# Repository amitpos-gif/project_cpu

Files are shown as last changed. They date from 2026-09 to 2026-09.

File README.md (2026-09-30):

# RISC-V RV32IM CPU Core & MCU — Structural VHDL

A fully functional five-stage pipelined RISC-V RV32IM processor designed from scratch in structural VHDL, taken through simulation, FPGA synthesis and on-hardware validation. The project is split into two parts: the pipelined CPU core, and a full MCU built on top of it.

---

## Projects

### 1. Pipelined RISC-V RV32IM CPU Core (`risc v cpu - project/`)

A five-stage pipelined implementation of the RISC-V RV32IM ISA (integer base + hardware multiply), built in structural VHDL from a single-cycle baseline.

**Pipeline stages:** IF → ID → EX → MEM → WB

**Key features:**
- Full data forwarding unit (EX/MEM and MEM/WB forwarding paths)
- Combinational hazard detection and stall unit
- Branch resolution with pipeline flush
- Hardware multiplier using the FPGA's embedded 8-bit multipliers (M extension)
- Structural HDL throughout — no behavioral shortcuts

**Verification & Validation:**
- Simulated in ModelSim against a RARS golden reference model
- IPC and functional correctness checked across a suite of test programs
- Mismatches analysed and debugged in simulation
- Synthesised and validated on an Intel FPGA with Signal-Tap on-hardware debug
- PPA (Power, Performance, Area) characterised and compared against the single-cycle baseline in Quartus

---

### 2. RV32IM-based MCU (`mcu - project/`)

An extension of the pipelined core into a full microcontroller unit.

**Added peripherals and features:**
- On-chip instruction and data memory
- Memory-mapped GPIO and I/O interface
- Vectored interrupt controller
- Hardware multicycle division accelerator with clock-domain-crossing synchronisation

---

## Tools & Flow

| Tool | Purpose |
|---|---|
| Intel Quartus | Synthesis, FPGA implementation, PPA analysis |
| ModelSim | RTL simulation and functional verification |
| Signal-Tap | On-hardware debug and signal probing |
| RARS | RISC-V golden reference model for verification |

**HDL:** Structural VHDL  
**Target FPGA:** Intel (Altera) FPGA  
**ISA:** RISC-V RV32IM

---

## Repository Structure

```
project_cpu/
├── risc v cpu - project/    # Five-stage pipelined RV32IM CPU core
│   ├── src/                 # VHDL source files (datapath, control, pipeline registers)
│   └── sim/                 # Simulation testbenches and scripts
└── mcu - project/           # Full MCU built on the pipelined core
    ├── src/                 # MCU peripherals and top-level integration
    └── sim/                 # MCU simulation files
```

---

## Background

Designed as part of the Advanced CPU Architecture course at Ben-Gurion University of the Negev, Hardware and VLSI & Semiconductor Devices tracks.

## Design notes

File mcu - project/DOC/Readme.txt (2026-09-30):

================================================================================
 RV32IM SINGLE-CYCLE MCU - FINAL PROJECT 2026
 Advanced CPU Architecture and Hardware Accelerators Lab 361-1-4693, BGU
 Submission: 206458333_318676061
================================================================================

 This file describes the content of every folder and subfolder in this
 submission, as required by clause 10 (Table 1) of the project definition.

 CONTENTS
   1. Submission tree at a glance
   2. DUT/     - synthesizable design sources
   3. TB/      - testbench
   4. SIM/     - ModelSim simulation script
   5. DOC/     - documentation
   6. Quartus/ - Quartus and hardware files
   7. How to reproduce the ModelSim simulation
   8. How to reproduce the Quartus compilation
   9. Conventions and things worth knowing

================================================================================
 1. SUBMISSION TREE AT A GLANCE
================================================================================

 206458333_318676061/
 |
 +-- DUT/
 |   +-- RV32IMscMCU/        32 synthesizable VHDL files (the design itself)
 |
 +-- TB/
 |   +-- RV32IMscMCU/        tb_mcu_top.vhd - the design testbench
 |
 +-- SIM/
 |   +-- RV32IMscMCU/        run_mcu_top.do - ModelSim compile + run script
 |
 +-- DOC/
 |   +-- Readme.txt          this file
 |   +-- Final_report.pdf    the full report (clause 9)
 |
 +-- Quartus/
     +-- RV32IMscMCU/        Signal-Tap file, SDC file and SOF file

 The RV32IMpipelinedMCU subfolders listed in Table 1 belong to the pipelined
 bonus task, which is not part of this submission, so they are not present.

================================================================================
 2. DUT/RV32IMscMCU  -  SYNTHESIZABLE DESIGN SOURCES
================================================================================

 Only design files - no testbench, no simulation script. All 32 files below
 compile without errors in ModelSim (VHDL-2008) and in Quartus.

 --- 2.1 Packages ------------------------------------------------------------

 cond_compilation_package.vhd
     The eight conditional-compilation parameters of the project: G_MODELSIM
     (1 = ModelSim, 0 = Quartus/FPGA), G_WORD_GRANULARITY, the ITCM/DTCM
     address width and word count (M9K / M4K variants), G_PC_WIDTH, G_MA_WIDTH
     and the three PLL divide/multiply ratios. Changing the memory
     configuration of the whole design is done here and only here.

 const_package.vhd
     Constants of the instruction set: opcodes, funct3/funct7 encodings, ALU
     operation codes and the immediate zero/one extension vectors used by
     IDECODE, EXECUTE and CONTROL.

 gpio_pkg.vhd
     The Table 5 memory map as named constants (PORT_LEDR 0x2000,
     PORT_HEX0..PORT_HEX5, PORT_SW 0x2010, PORT_PB 0x2014). It documents the
     address map in one place; the decoders themselves compare the address
     bits directly, which costs no logic.

 aux_package.vhd
     The central component-declaration registry of the project. Every entity
     in the design is declared here once, so a structural file only needs
     "use work.aux_package.all" instead of repeating component declarations.

 --- 2.2 Generic building blocks ---------------------------------------------

 BidirPin.vhd
     Bidirectional pin/bus driver. Used as the "Bi-directional Data BUS" block
     of Figure 1: it drives the shared byte bus during a CPU write and reads
     it back on every cycle.

 tristate_byte.vhd
     8-bit tri-state driver. Every peripheral read port uses one to place its
     byte on the shared Data bus when its chip select and MemRead are active.

 d_latch_byte.vhd
     8-bit transparent D-latch, the GPO register of Figure 5. It is
     transparent only while En = '1' AND clk = '0'; the low phase of SMCLK is
     the safe write window, after the single-cycle combinational chain has
     settled.

 hex7seg_decoder.vhd
     Converts the low nibble of a latched byte into an active-low 7-segment
     pattern for one HEX display.

 --- 2.3 CPU core ------------------------------------------------------------

 IFETCH.VHD
     Program counter, PC+4 adder, next-PC decision mux (reset / hold / jalr /
     branch-taken or jal / PC+4) and the ITCM, an altsyncram ROM initialized
     from a benchmark ITCM.hex file.

 IDECODE.VHD
     Instruction field extraction, the 32x32 register file, sign extension of
     all five immediate formats and the write-back mux (ALU / memory /
     multiplier / accelerator result).

 EXECUTE.VHD
     The ALU and the branch-address generation unit: all RV32I arithmetic,
     logic, shift and comparison operations, and the branch-taken decision.

 CONTROL.VHD
     Main control unit. Decodes the opcode into the datapath control signals
     and also implements the interrupt protocol side of the CPU: the PC hold,
     the INTA acknowledge cycle, the vector fetch and the GIE set/clear rules.

 DMEMORY.VHD
     The DTCM, an altsyncram single-port RAM initialized from a benchmark
     DTCM.hex file and clocked on NOT MCLK so that the address register is
     loaded with the write clock.

 MUL.vhd
     16-bit multiplier built from four 8-bit partial products, the RV32IM
     multiply extension.

 sync.vhd
     Two-flip-flop operand synchronizer (Figure 10b) that carries the two
     divider operands from the MCLK domain into the faster DIVCLK domain.

 divider_accelerator.vhd
     Unsigned restoring divider (Figure 9). DIVRST loads both operands in
     parallel and one quotient bit is produced on every enabled DIVCLK edge.

 RV32I_CORE.vhd
     Structural top of the CPU: IFETCH, IDECODE, EXECUTE, CONTROL, DMEMORY,
     MUL, sync and divider_accelerator, plus the divider handshake state
     machine, the MCLK cycle counter and the GIE / INTA / INTR interface to
     the interrupt controller.

 --- 2.4 Address decoders ----------------------------------------------------

 addr_decoder_gpio.vhd
     Chip selects for PORT_LEDR, PORT_HEX0/1, PORT_HEX2/3, PORT_HEX4/5 and
     PORT_SW.

 addr_decoder_basic_timer.vhd
     Chip selects for BTCTL1, BTCTL2, BTCMPR0, BTCMPR1 and BTCAPR.

 addr_decoder_interrupt.vhd
     Chip selects for IE (0x202C), IFG (0x202D) and TYPE (0x202E).

 --- 2.5 Peripherals ---------------------------------------------------------

 gpio_peripherals.vhd
     The GPIO block of Figure 5: the LEDR and HEX0..HEX5 D-latches, their
     7-segment encoders, the tri-state read-back drivers and the SW input
     port, all sharing one byte-wide Data bus.

 pushbutton_peripheral.vhd
     The KEY1..KEY3 input peripheral. It samples the buttons in the SMCLK
     domain, exposes their level as the read-only PORT_PB register (0x2014)
     and produces a one-cycle active-high press event per key for the
     interrupt controller.

 bit_Timer.vhd
     The N-bit up counter at the heart of the Basic Timer.

 OUTPUT_UNIT.vhd
     The output compare / PWM unit: the EQU0 and EQU1 comparators against
     BTCL0 and BTCL1 and the PWM output flip-flop, in both BTOUTMD modes.

 basic_timer.vhd
     The Basic Timer itself: the BTCTL1, BTCTL2, BTCMPR0, BTCMPR1 and BTCAPR
     registers, the BTSSEL clock-source divider, BTHOLD and BTCLR, the
     capture unit with its two-flip-flop crossing back into SMCLK, and the
     BTINT source selection that drives BTIFG.

 basic_timer_top.vhd
     Structural wrapper that joins basic_timer to its address decoder and
     qualifies the four writable registers with MemWrite.

 interrupt_controller.vhd
     The IE, IFG and TYPE registers, the event capture of BTIFG and the three
     key requests, the priority encoder (Basic Timer 0x10, KEY1 0x14,
     KEY2 0x18, KEY3 0x1C) and the INTR output.

 interrupt_controller_top.vhd
     Structural wrapper: the controller, its address decoder, and the bus
     interface that drives IE/IFG/TYPE on the Data bus for software reads and
     drives TYPE during the active-low INTA acknowledge, where no address is
     placed on the Address bus.

 --- 2.6 Clock tree and tops -------------------------------------------------

 PLL.vhd
     Altera altpll megafunction wrapper with configurable divide/multiply
     ratios. It is instantiated only when G_MODELSIM = 0, i.e. in Quartus.

 clock_tree.vhd
     The Clock Tree of Figure 1: three PLLs producing MCLK for the CPU, SMCLK
     for the peripherals and ACCELCLK (DIVCLK) for the divider accelerator,
     plus the combined locked indication.

 mcu_top.vhd
     The MCU: the RV32I core, the BUS Interface Logic (the ALU address tap,
     the bidirectional Data bus and the peripheral read-return path) and all
     peripherals - GPIO, pushbuttons, Basic Timer and interrupt controller.
     This is the entity the testbench instantiates.

 mcu_system.vhd
     The board-level top entity: the Clock Tree plus mcu_top, with the DE10
     pin names (CLOCK_50, KEY0..KEY3, SW, LEDR, HEX0..HEX5, PWM, CAPIN1/2).
     KEY0 is inverted into the active-high system reset, which is also held
     while the PLLs have not locked. This is the top entity for Quartus.

================================================================================
 3. TB/RV32IMscMCU  -  TESTBENCH
================================================================================

 tb_mcu_top.vhd
     The design testbench. It instantiates mcu_top and plays the role of the
     Clock Tree, because clock_tree only builds its PLLs when G_MODELSIM = 0
     and therefore has no outputs in simulation. It generates MCLK and SMCLK
     at 25 MHz, synchronous and in the same phase as d_latch_byte requires,
     and DIVCLK at 125 MHz, holds reset for five MCLK cycles and then lets
     the program in the ITCM run. KEY1..KEY3, SW, CAPIN1 and CAPIN2 start
     idle and can be driven from the ModelSim Objects/Wave window, or from
     the stimulus process, to exercise the peripherals and the interrupts.

================================================================================
 4. SIM/RV32IMscMCU  -  MODELSIM SIMULATION SCRIPT
================================================================================

 run_mcu_top.do
     The ModelSim script that builds and runs the simulation: it creates a
     fresh work library, compiles the packages, the core, the shared bus and
     GPIO, the Basic Timer and the interrupt system, then the testbench, all
     with vcom -2008; elaborates work.tb_mcu_top against the altera_mf
     library; opens a waveform grouped into CLOCKS AND RESET, CPU,
     PERIPHERAL BUS, INTERRUPTS and BOARD INPUTS AND OUTPUTS; and runs the
     simulation for 100 us.

     The design sources are read from ../../DUT/RV32IMscMCU and the
     testbench from ../../TB/RV32IMscMCU, through the DUTDIR and TBDIR
     variables at the top of the script, so it runs straight out of
     this folder without copying any file.

     See clause 7 below for how to run it.

================================================================================
 5. DOC  -  DOCUMENTATION
================================================================================

 Readme.txt
     This file: the description of every folder and subfolder of the
     submission.

 Final_report.pdf
     The full project report required by clause 9: the top-level block
     diagram, the RTL Viewer results, the three PPA tables (area,
     performance, power) with their Quartus screenshots, a short description
     of each HDL source file, the waveform analysis of benchmark applications
     test1 to test4, and the conclusions.

================================================================================
 6. Quartus/RV32IMscMCU  -  QUARTUS AND HARDWARE FILES
================================================================================

 test.sdc
     The Synopsys Design Constraints file. It creates the 20 ns (50 MHz)
     board clock on the CLOCK_50 port and then calls derive_pll_clocks and
     derive_clock_uncertainty so that TimeQuest also knows the three PLL
     output clocks of the Clock Tree.

 stp1.stp
     The Signal-Tap II logic analyzer file used for the on-board (ISMCE)
     verification: the instance, the sampling clock and the captured signal
     set used to record the MCU behaviour on the real FPGA.

 LAB_5_PIP.sof
     The SRAM Object File produced by the Quartus compilation, i.e. the
     bitstream downloaded to the DE10 board.

 No intermediate Quartus files (db, incremental_db, output_files, qsf, qpf)
 are included, as required by Table 1.

================================================================================
 7. HOW TO REPRODUCE THE MODELSIM SIMULATION
================================================================================

 The design uses sized bit-string literals (const_package) and "elsif
 generate" (IFETCH, RV32I_CORE), so VHDL-2008 is mandatory: every vcom call
 must carry -2008. It also uses altsyncram, so the altera_mf library must be
 available (it is precompiled in ModelSim - Intel FPGA Edition).

   1. Start ModelSim and set SIM/RV32IMscMCU as the working directory.
   2. At the ModelSim prompt:   do run_mcu_top.do
   3. The script reads the design from ../../DUT/RV32IMscMCU and the
      testbench from ../../TB/RV32IMscMCU, compiles everything into a
      fresh work library, opens the waveform and runs 100 us. Nothing
      has to be copied between the folders.

 Which benchmark program runs is decided by the init_file attribute of the
 two altsyncram instances - IFETCH.VHD for the ITCM and DMEMORY.VHD for the
 DTCM. Both hold an absolute path to a "bin/M9K-intel" folder of one
 benchmark application. To run a different test, point both paths at the
 ITCM.hex and DTCM.hex of that test and recompile those two files. A missing
 or mistyped path makes vsim stop with a fatal error at time 0.

================================================================================
 8. HOW TO REPRODUCE THE QUARTUS COMPILATION
================================================================================

   1. Create a Quartus project for the DE10 device and add all 32 VHDL files
      from DUT/RV32IMscMCU. Set the VHDL input version to VHDL 2008.
   2. Set mcu_system as the top-level entity.
   3. Set G_MODELSIM = 0 in cond_compilation_package.vhd so that clock_tree
      and RV32I_CORE instantiate the PLLs instead of taking the clocks
      directly from their input ports.
   4. Add test.sdc to the project as the timing constraint file.
   5. Compile, then program the board with the resulting SOF file, and open
      stp1.stp for the Signal-Tap capture.

================================================================================
 9. CONVENTIONS AND THINGS WORTH KNOWING
================================================================================

 * G_MODELSIM selects the whole build target. With G_MODELSIM = 1 the clocks
   arrive directly on the input ports, which is what the testbench drives;
   with G_MODELSIM = 0 the PLLs of the Clock Tree generate them.

 * SMCLK must be synchronous with MCLK and in phase with it. The GPIO output
   registers are transparent D-latches that open only while SMCLK is low, and
   that low phase is what guarantees the address and data have settled after
   the single-cycle combinational chain.

 * The peripheral Data bus is one shared byte-wide bidirectional bus. Every
   peripheral drives it through a tri-state and releases it to 'Z' otherwise,
   so at most one driver is ever active. BTCAPR is the exception: it is a
   32-bit word register and is returned to the CPU on a dedicated 32-bit path
   in mcu_top rather than through the byte bus.

 * Interrupt signal polarity: INTR and the key requests are active high, INTA
   is active low. During INTA the controller drives TYPE onto the Data bus
   without an address, which is why TYPE has priority over the address-decoded
   read paths in interrupt_controller_top.

 * Interrupt vectors: RESET/NMI type 0x00, Basic Timer type 0x10 (highest
   maskable priority), KEY1 type 0x14, KEY2 type 0x18, KEY3 type 0x1C
   (lowest). Bits 7:6 and 1:0 of IE and IFG are reserved and always read 0.

 * All peripheral addresses are byte addresses inside the 14-bit data address
   space; the I/O region starts at 0x2000.

================================================================================
 End of Readme.txt
================================================================================

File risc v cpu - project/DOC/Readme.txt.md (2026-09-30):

# Lab 5 — RV32IM Pipelined Processor (Course 361-1-4693, BGU)

This project converts the supplied **single-cycle RV32IM** core into a fully **pipelined 5-stage architecture** (IF · ID · EX · MEM · WB) written in **structural VHDL**. It supports the user-level RV32I instruction set plus the `MUL` extension, and targets the **DE10-Standard** board (Cyclone V `5CSXFC6D6F31C6`). The design adds hazard hardware (forwarding, load/MUL-use stalling, branch flush), a **2-stage pipelined multiplier**, an on-chip PLL for the core clock, and a SignalTap-oriented debug instrumentation layer. The authoritative datapath is the figure `rv32ipipeline.png`.

---

## Top Level

### `RV32I_CORE_PIPLINE.vhd`
Structural top of the pipeline core. Instantiates all five stages, the four pipeline registers, the three hazard units, the multiplier stages, and the PLL. Also contains two non-datapath blocks: a **debug shadow pipeline** that mirrors the instruction word and PC through EX/MEM/WB for observation (so the real registers needn't be widened), and the **instrumentation counters** (`CLKCNT`, `STCNT`, `FHCNT`) plus the SignalTap trigger (`STRIGGER`). Hazard enables are derived here: a stall freezes PC + IF/ID and bubbles ID/EX, while a flush squashes IF/ID, ID/EX and EX/MEM — with flush taking priority over stall.

### `PIPLINE_USER_INTERFACE.vhd`
Board-level wrapper for the DE10-Standard. Maps physical pins (`KEY` for reset/enable, `SW[7:0]` for the breakpoint address `BPADDR`) onto the core, applying reset polarity inversion. Internal taps are observed via SignalTap rather than driven to output pins.

---

## Pipeline Stages

### `IFETCH.VHD`  *(Stage 1 — IF)*
Fetches the instruction at the current PC from the ITCM and computes `PC+4`. Selects the next PC among `PC+4`, the branch/jump target, and the JALR target. **Branches and jumps are resolved at stage 4 (MEM)**, so the redirect inputs (`addr_gen`, `br_or_jump_taken`, `Jalr_ctrl`, `alu_res`) come from the *registered* EX/MEM outputs. PC advance is gated by the stall enable.

### `IDECODE.vhd`  *(Stage 2 — ID)*
Decodes the instruction, reads the register file, and generates the sign-extended immediate. The register-file **write port is driven by the retiring (MEM/WB) instruction** — write-back data, `rd`, `RegWrite`, `RegDst` and `PC+4` all arrive from MEM/WB, so the JAL/JALR link-address MUX inside this stage acts on the correct instruction.

### `EXECUTE.VHD`  *(Stage 3 — EX)*
Performs the ALU operation and computes the branch/jump target address (`adder_gen`). Contains the **operand-forwarding MUXes** for both ALU inputs (driven by `Forward_Ain`/`Forward_Bin` from the forwarding unit). The forwarded rs2 value is also captured for store data, with the ALUSrc MUX applied *after* forwarding on the B path so store addresses aren't corrupted. Launches **MUL stage 1** (the partial products) when `MULOp` is set.

### `DMEMORY.VHD`  *(Stage 4 — MEM)*
Data memory (DTCM, RAM). Reads/writes the word-addressed memory; the byte address from the ALU result is sliced (`>>2`) down to the DTCM word index. Store data is the forwarded rs2. Operates in parallel with **MUL stage 2** in this stage.

### `WB_MUX.vhd`  *(Stage 5 — WB)*
Write-back select. Chooses the value written to the register file among the **ALU result**, the **DTCM load data**, and the **MUL result** (the JAL/JALR PC+4 link is inserted on the IDECODE side). Controlled by `WBSrc`/`MemtoReg`.

---

## Pipeline Registers

Each register latches on the (PLL-derived) clock. `IF_ID` and `ID_EX` honor stall (hold/bubble) and flush; `EX_MEM` honors flush; all reset to a NOP-equivalent state.

| File | Boundary | Key payload carried |
|---|---|---|
| `IF_ID_REG.vhd` | IF → ID | `pc`, `pc_plus4`, `instruction` (+ `ena`/`flush`) |
| `ID_EX_REG.vhd` | ID → EX | `pc`, `pc_plus4`, `read_data1/2`, `imm32`, `rs1/rs2/rd`, full control bundle (`ALUOp`, `ALUSrc`, `UpperImm`, `MULOp`, `Branch`, `Jal`, `Jalr`, `MemRead/Write`, `RegWrite`, `MemtoReg`, `RegDst`, `WBSrc`) |
| `ex_mem_reg.vhd` | EX → MEM | `pc_plus4`, `read_data1/2`, `imm32`, `rs1/rs2/rd`, `Alu_Res`, `Adder_gen`, MUL stage-1 partials `p0..p3`, `MULOp`, `br_or_jump_taken`, `Jalr_ctrl`, and MEM/WB control |
| `MEM_WB_REG.vhd` | MEM → WB | `pc_plus4`, `alu_res`, `mem_data`, `mul_res`, `rd`, `RegWrite`, `MemtoReg`, `RegDst`, `WBSrc` |

---

## Hazard Hardware

### `forwarding_unit.vhd`
Compares the ID/EX source registers (`rs1`, `rs2`) against the destination registers in **EX/MEM** and **MEM/WB** (gated by their `RegWrite`), emitting 2-bit `Forward_Ain`/`Forward_Bin` selects to bypass operands into EXECUTE. Resolves EX-hazards (one ahead) and MEM-hazards (two ahead) without stalling.

### `STALL_UNIT.vhd`
Detects the **load-use** and **MUL-use** interlocks: if the instruction in EX is a load (`MemRead`) or a multiply (`MULOp`) and its `rd` matches an `rs1`/`rs2` of the instruction in IF/ID, it asserts `Stall` for one cycle (freeze PC + IF/ID, bubble ID/EX) — the case forwarding alone cannot cover.

### `FLUSH_UNIT.vhd`
Generates the squash signal when a branch/jump (or JALR) is **taken**, reading the *registered* EX/MEM redirect bits (resolution at stage 4). The flush kills the wrong-path instructions sitting in IF/ID, ID/EX and EX/MEM.

---

## Multiplier (2-stage)

### `MUL_STAGE1.VHD`
Runs in **EX**. Produces the four 16-bit partial products (`p0..p3`) from the operands; these are carried through EX/MEM.

### `MUL_STAGE2.VHD`
Runs in **MEM**. Combines the partial products into the final 32-bit result, preserving the full-width intermediate carry. The result feeds the WB MUX.

---

## Clocking & Memory

### `PLL.vhd`
Altera ALTPLL megafunction. On the FPGA it converts the **50 MHz** board clock to the **75 MHz** core clock (×3 ÷2). In ModelSim the PLL is bypassed (`mclk = clk_i`) via the `MODELSIM` generate guard.

### Memory (ITCM / DTCM)
Word-addressed on-chip memories initialized from Intel-HEX files. Instruction memory lives inside `IFETCH`; data memory is `DMEMORY.VHD`.

---

## Support Packages

| File | Role |
|---|---|
| `aux_package.vhd` | Component declarations for all entities (structural binding). |
| `const_package.vhd` | Global constants / widths (`G_PC_WIDTH`, `G_ADDRWIDTH`, `G_DATA_WORDSNUM`, …). |
| `cond_compilation_package.vhd` | Conditional-compilation switches (e.g. `G_MODELSIM`, `G_WORD_GRANULARITY`). |
| `CONTROL.VHD` | Main control decoder: maps opcode/funct of the IF/ID instruction to the full control bundle. |

---

## Debug & Instrumentation

The core exposes per-stage **PC** and **instruction** taps (`IFpc`/`IFinstruction` … `WBpc`/`WBinstruction`), free-running `CLKCNT`, stall counter `STCNT`, flush counter `FHCNT`, and a `STRIGGER` pulse when the IF-stage PC (word index) equals `BPADDR`. The EX/MEM/WB instruction and PC taps are produced by an observation-only **shadow pipeline** that mirrors the bubble/hold behavior of the real registers.

---

## Toolchain

- **Quartus Prime** — synthesis, place-and-route, pin assignment, programming.
- **ModelSim Intel FPGA Edition** — RTL/gate simulation.
- **TimeQuest** — static timing analysis (PLL-derived clock constrained via `derive_pll_clocks`).
- **SignalTap** — in-system observation of the stage taps and counters.

---

## Hardware Test Case

Tested on the **DE10-Standard** FPGA board: `KEY` buttons drive reset/enable, `SW[7:0]` set the breakpoint address (`BPADDR`), and SignalTap captures the pipeline state when the IF-stage PC reaches the breakpoint.

---

By: yuval elron and amit postelnik

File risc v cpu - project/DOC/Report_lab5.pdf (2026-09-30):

# Laboratory 5 Report

Conversion of a Single-Cycle RV32IM Processor into a Five-Stage Pipelined Micro-Architecture

Submitted by | Yuval Elron – 318676061 Amit Postelnik – 206458333
Course | Advanced CPU Architecture & Hardware Accelerators (361-1-4693)
Target Device | Intel Cyclone V 5CSXFC6D6F31C6 (DE10-Standard)
Tool-chain | Quartus Prime 21.1 Lite • ModelSim • TimeQuest • SignalTap
ISA | RV32IM (MULDIV partial)
Report file | Report_lab5.pdf

Lab 5 – RV32IM Pipelined Processor | Report_lab5.pdf

## 1. Introduction and Lab Context

This report documents the conversion of a single-cycle RV32IM (MULDIV-partial) processor into a fully pipelined five-stage RISC-V micro-architecture, implemented in structural VHDL and synthesised for the Intel Cyclone V FPGA on the DE10-Standard board. The single-cycle design delivered in the previous task served as the functional reference: its datapath was sliced into the five classical RISC pipeline stages – Instruction Fetch (IF), Instruction Decode / register read (ID), Execute / address calculation (EX), Data-Memory access (MEM) and Write-Back (WB) – with pipeline registers inserted at every stage boundary.

Pipelining overlaps the execution of consecutive instructions so that, in steady state, one instruction is retired every clock cycle. Because each stage now performs only a fraction of the original combinational work, the critical path is dramatically shortened and the maximum operating frequency increases substantially. This benefit is not free: overlapping execution introduces data hazards (an instruction needing a result that has not yet been written back) and control hazards (the next fetch address depending on a branch that has not yet resolved). The design therefore adds three pieces of dedicated hazard hardware: a forwarding (bypass) unit that routes freshly computed results back to the EX stage, a combinational stall-detection unit that inserts bubbles for the unavoidable load-use and multiply-use cases, and a flush unit that squashes wrong-path instructions once a branch or jump is resolved.

In accordance with the lab specification, conditional branches and unconditional jumps are resolved in pipeline stage 4 (MEM), and the multiplier is split across two pipeline stages (partial-product generation in EX, accumulation in MEM) so that it does not dominate the critical path. The remainder of this report presents the top-level structure, the RTL-Viewer netlists, a quantitative Power–Performance–Area (PPA) comparison between the single-cycle and pipelined designs, a description of every HDL source file, and an analysis of the simulation waveforms used to validate system timing against the benchmark applications.

## 2. Top-Level Block Review Diagram

The synthesised top-level entity is PIPLINE_USER_INTERFACE, the board wrapper that adapts the logical core (RV32I_CORE_PIPLINE) to the physical DE10-Standard pins. The wrapper exposes only three input ports – the 50 MHz oscillator CLOCK_50, the active-low push-buttons KEY[3:0]
(KEY0 is inverted to form the active-high reset), and the slide switches | (the lower eight feed
the breakpoint address BPADDR_i). It has no output ports: all observability is provided internally through SignalTap taps (CLKCNT_o, STCNT_o, FHCNT_o and the core buses), which is why the pin count drops sharply relative to the single-cycle top entity.
Internally the core is a structural composition of fourteen sub-modules: a PLL (50 MHz →
core clock), the five stage blocks (Ifetch, Idecode, Execute, dmemory, write-back MUX), the four pipeline registers (IF_ID_REG, ID_EX_REG, EX_MEM_REG, MEM_WB_REG), the control decoder, and the three hazard units (FORWARDING_UNIT, STALL_UNIT, FLUSH_UNIT). The two-stage multiplier is embedded inside the EX and MEM blocks. Figure 1 shows the top-level RTL-Viewer elaboration of this wrapper, which acts as the block-review diagram of the complete design.

SW[7:0]

25 MHz

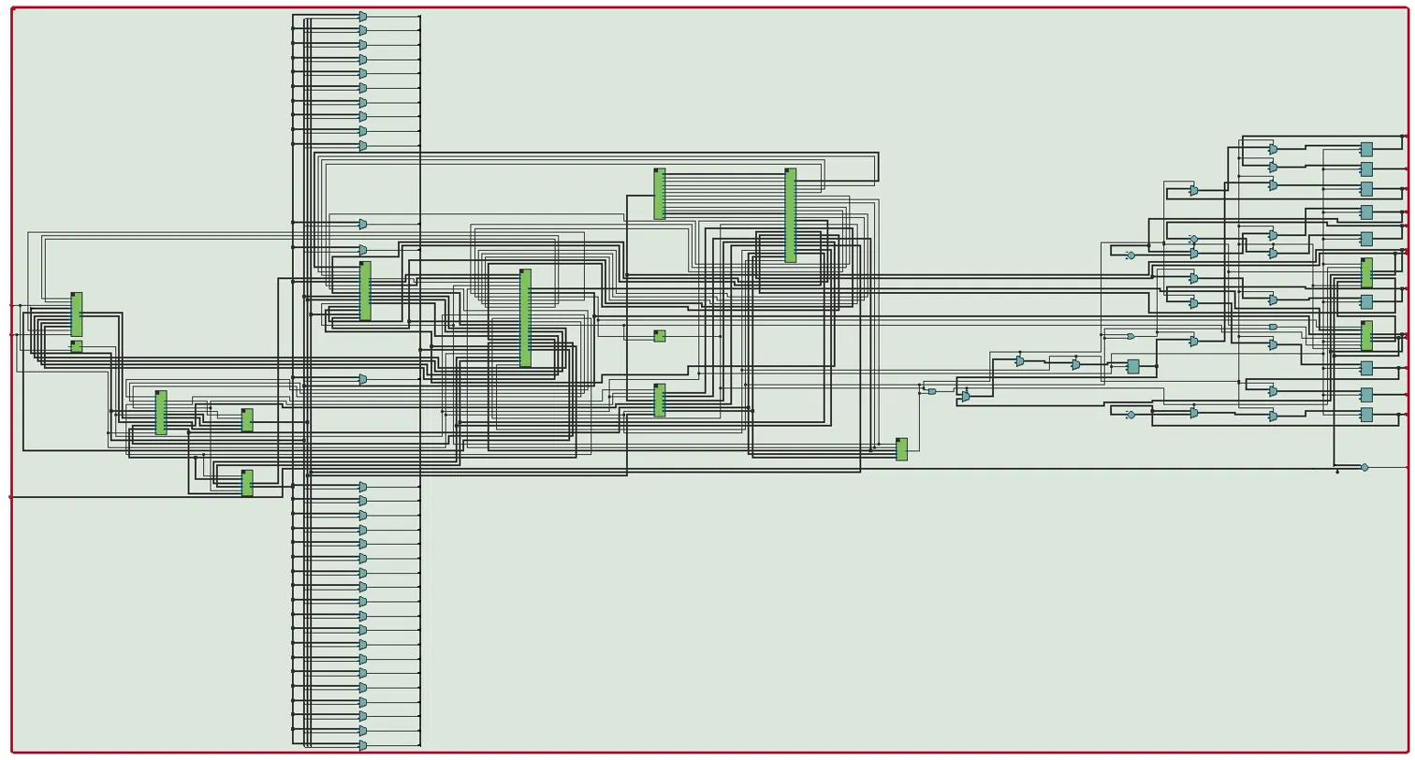
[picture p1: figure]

Figure 1: Top-level block / RTL elaboration of the pipelined RV32IM design (PIPLINE_USER_INTERFACE), showing the five pipeline stages separated by pipeline registers and the surrounding hazard logic.

## 3. RTL Viewer Results

The Quartus RTL Viewer presents the post-elaboration, technology-independent netlist inferred from the VHDL source. Comparing the two designs makes the structural effect of pipelining explicit. In the single-cycle netlist (Figure 2) the datapath forms one long combinational chain from the instruction memory, through the register file and ALU, to the data memory and back to the register file, with no intermediate state. In the pipelined netlist (Figure 3) that chain is interrupted by four banks of pipeline registers, partitioning the logic into five shorter stages and adding the forwarding, stall and flush logic that connects across stage boundaries.

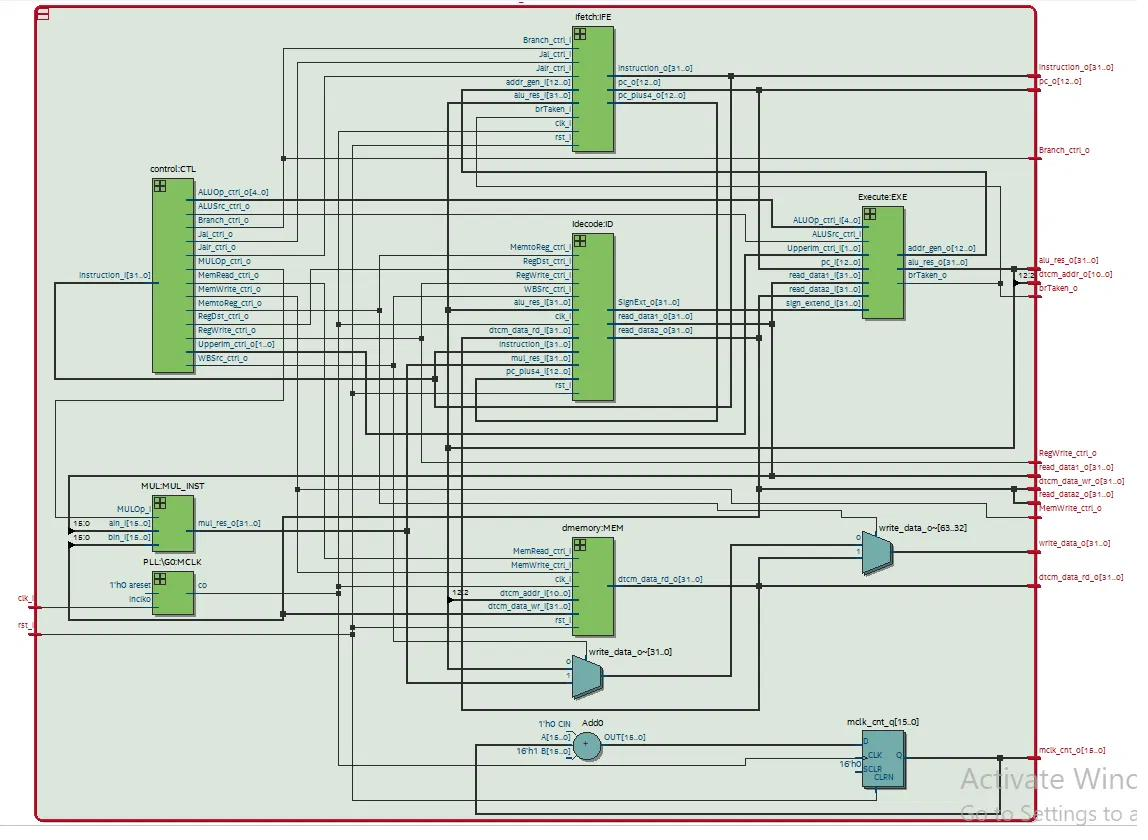
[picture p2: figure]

Figure 2: RTL-Viewer netlist of the original single-cycle RV32IM design. The datapath is a single combinational path with no pipeline registers.

Figure 3: RTL-Viewer netlist of the pipelined RV32IM design. Four pipeline-register banks split the datapath into five stages; additional hazard logic bridges the stage boundaries.

## 4. Clause 7 – PPA Characterisation (Area, Performance, Power)

This section reports the three Power–Performance–Area tables required by clause 7, each comparing the single-cycle and pipelined implementations. The figures are taken directly from the Quartus Fitter, TimeQuest and Power-Analyzer reports, whose screen captures are attached immediately after each table as mandated by the specification.

### 4.1 Area

Area

| Logic elements | Registers | I/O pins | Embedded memory bits | Embedded 9-bit Multipliers | PLLs
Single-Cycle RV32IM | 1,436 | 1,311 | 270 | 131,072 | 3 | 1
Pipelined RV32IM | 1,456 | 1,760 | 15 | 131,072 | 4 | 1

Note: Attaching the print screen of the Quartus Area report is mandatory
Table 1: Area / resource utilisation of the single-cycle versus pipelined RV32IM designs (Quartus Fitter Flow Summary).

The pipeline adds ~449 registers (1,311 → 1,760), the cost of the four pipeline-register banks, while combinational logic grows only marginally (1,436 → 1,456 logic elements). The embedded 9-bit multiplier count rises from 3 to 4 because the multiplier is now split across two stages. The pin count collapses from 270 to 15 because the pipelined top entity exposes only the clock, keys and switches and relies on internal SignalTap taps rather than routing buses to physical pins.

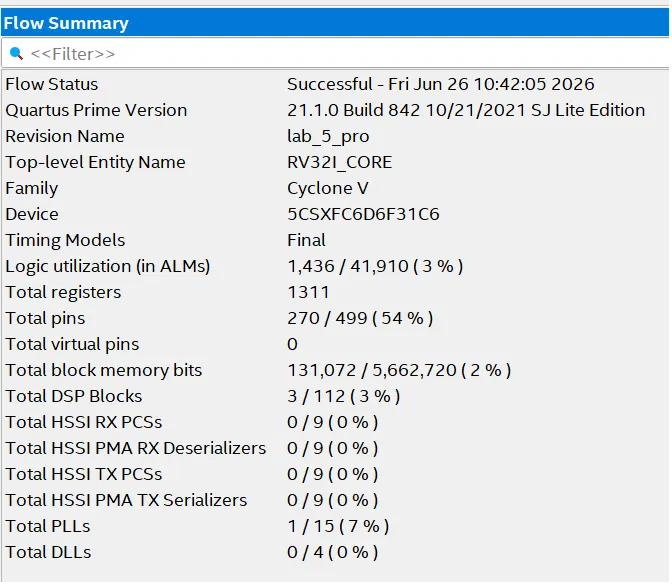
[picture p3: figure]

Figure 4: Quartus Flow Summary (area) report – single-cycle RV32IM.

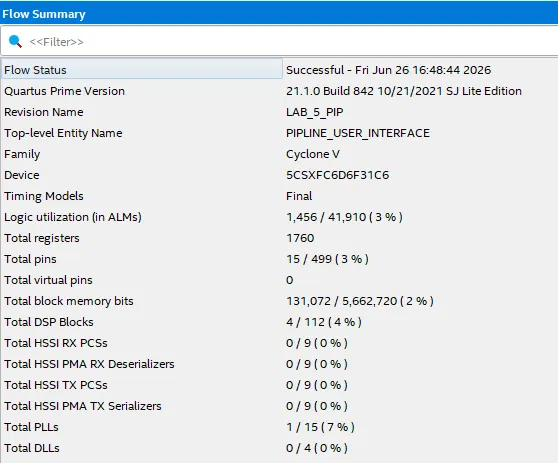
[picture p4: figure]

Figure 5: Quartus Flow Summary (area) report – pipelined RV32IM.

### 4.2 Performance (fmax

### and Critical Path)

Performance

| fmax | Critical path (what is the slowest submodule and why does it cause the critical path) | f MCLK (= fsysclk)
Single-Cycle RV32IM | 38.05 MHz | Long path: DTCM read → decode → Execute ALU/shifter mux chain (brl_shr / Mux60). Memory access, decode and execution all fall inside one cycle.
Pipelined RV32IM | 70.32 MHz | Path: DTCM (data_memory) read port q_a[31:0] → MEM_WB_REG. Stage isolation removes the memory–decode–execute chain, so the memory read alone now sets the limit.

Table 2: Performance comparison: maximum clock frequency and critical-path analysis (Quartus TimeQuest).

Pipelining nearly doubles fmax

(38.05 → 70.32 MHz). The theoretical upper bound for a perfectly balanced 5-stage pipeline is 5 × f

single; the realised speed-up is lower because the stages are not perfectly balanced – the synchronous DTCM read, feeding the MEM/WB register, is the slowest stage and now defines the critical path, as confirmed by the Map-Viewer trace below.

Figure 6: Quartus TimeQuest f
max

report – single-cycle RV32IM (38.05 MHz).

Figure 7: Quartus TimeQuest f
max

report – pipelined RV32IM (70.32 MHz).

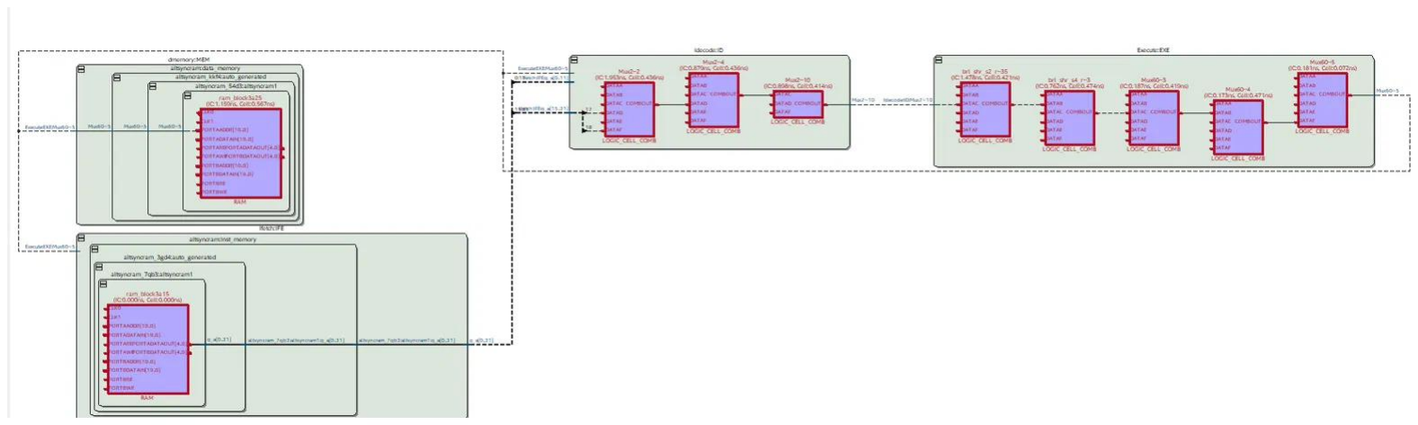
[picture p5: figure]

Figure 8: Critical-path Technology-Map Viewer – single-cycle: the path spans data memory, the decode stage and the Execute ALU/shifter mux chain.

25 MHz

25 MHz

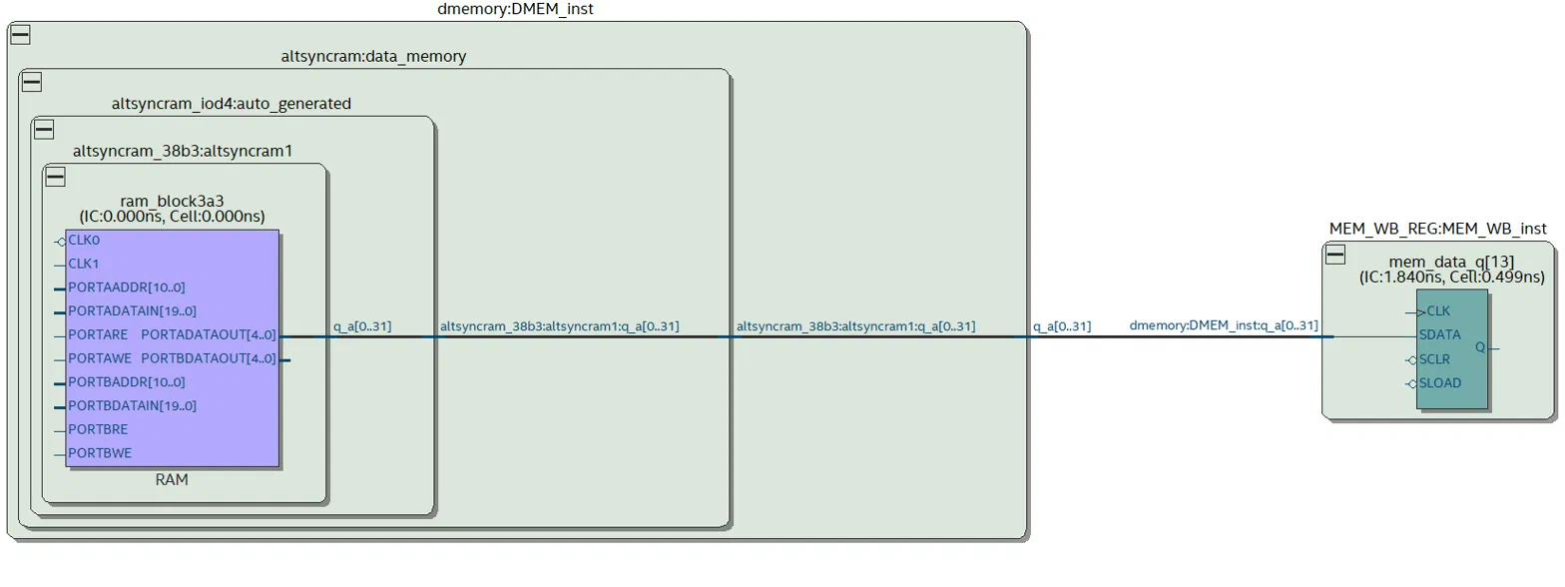
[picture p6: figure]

Figure 9: Critical-path Technology-Map Viewer – pipelined: the path is reduced to the DTCM read port feeding the MEM_WB_REG register.

### 4.3 Power

Power

| Total power consumption | Static power consumption | Dynamic power consumption | I/O power consumption
Single-Cycle RV32IM | 448.06 mW | 415.31 mW | 19.01 mW | 13.74 mW
Pipelined RV32IM | 447.79 mW | 415.31 mW | 22.38 mW | 10.10 mW

Note: Attaching the print screen of the Quartus Power report is mandatory
Table 3: Power-dissipation comparison (Quartus PowerPlay Power Analyzer, thermal power).

Total dissipation is essentially unchanged (≈448 mW) and is dominated by the device static power (415.31 mW), which is identical for both designs because it depends on the Cyclone V silicon rather than the logic. Core dynamic power rises slightly in the pipeline (19.01 → 22.38 mW) due to the extra register toggling, while I/O power falls (13.74 → 10.10 mW) because far fewer pins are driven. As noted in both reports, the estimation confidence is Low because no switching-activity (toggle-rate) file was supplied, so the dynamic figures should be read as first-order estimates.

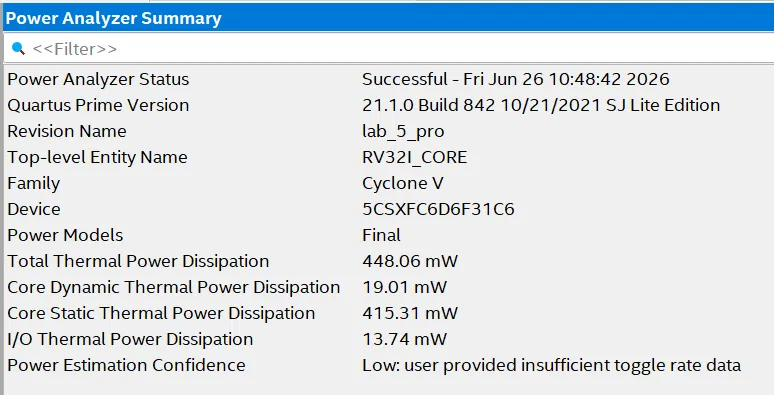
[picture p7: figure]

Figure 10: Quartus Power-Analyzer report – single-cycle RV32IM.

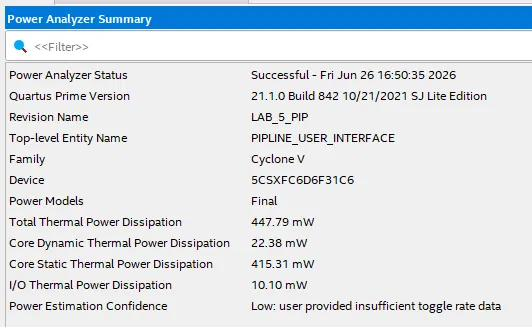
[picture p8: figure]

Figure 11: Quartus Power-Analyzer report – pipelined RV32IM.

## 5. HDL Source File Descriptions

The design is fully structural: a top wrapper instantiates the core, which in turn instantiates the stage blocks, pipeline registers and hazard units. Table 5 lists every HDL source file with a short description of its role in the pipeline.

HDL Source File | Description
PIPLINE_USER_INTERFACE.vhd | Board top-level wrapper for the DE10-Standard. Maps CLOCK_50, KEY[3:0] and SW[9:0] to the core; inverts KEY0 to an active-high reset and routes SW[7:0] to the breakpoint address. No output ports – internal signals are observed via SignalTap.
RV32I_CORE_PIPLINE.vhd | The logical pipelined core. Structurally instantiates the PLL, the five stage blocks, the four pipeline registers, the control decoder and the three hazard units, and wires the forwarding, stall and flush datapaths between them.
PLL.vhd | Phase-locked-loop IP wrapper. Generates the core clock from the 50 MHz board oscillator (×3/÷2 → 75 MHz).
IFETCH.VHD | Stage 1 (IF). Holds the program counter and the instruction memory (ITCM); selects the next PC among PC+4, the branch/jump target and the JALR target. Stalls when PCwrite is de-asserted.
IF_ID_REG.vhd | IF/ID pipeline register. Latches the fetched instruction and PC (and PC+4) for use by the decode stage; supports flush and stall.
CONTROL.VHD | Main control decoder. Decodes the instruction opcode/funct fields into the control bundle (RegWrite, ALUSrc, MemRead/Write, Branch, Jal/Jalr, ALUOp, MULOp, WBSrc, etc.).
IDECODE.vhd | Stage 2 (ID). Contains the 32×32 register file and the immediate sign-extension logic; reads rs1/rs2 and performs the write-back write in the same stage.
ID_EX_REG.vhd | ID/EX pipeline register. Carries the operands, immediate, PC, source/destination register indices and the full control bundle into the execute stage.
EXECUTE.VHD | Stage 3 (EX). Houses the ALU, the branch-condition and target computation, the operand-forwarding and ALUSrc multiplexers and multiplier stage 1 (partial-product generation).
MUL_STAGE1.VHD | First half of the two-stage multiplier (runs in EX). Produces the four 16-bit partial products P0–P3 from the low/high halves of the operands.
EX_MEM_REG.vhd | EX/MEM pipeline register. Carries the ALU result, the store data, the partial products and the control bundle into the memory stage; holds the branch instruction itself for stage-4 resolution.
DMEMORY.VHD | Stage 4 (MEM). Contains the data memory (DTCM) and multiplier stage 2; performs loads/stores and, in parallel, combines the partial products into the final 32-bit multiply result.
MUL_STAGE2.VHD | Second half of the multiplier (runs in MEM). Sums the shifted partial products into the 32-bit product, correcting the carry-propagation that the original single-stage multiplier dropped.
MEM_WB_REG.vhd | MEM/WB pipeline register. Carries the memory-read data, the ALU/MUL result, the destination index and the write-back control into the final stage.
WB_MUX.vhd | Stage 5 (WB). Selects the value written back to the register file among the ALU/MUL result, the loaded memory word and the link value (PC+4) for JAL/JALR.

HDL Source File | Description
forwarding_unit.vhd | Data-forwarding (bypass) unit. Compares the EX-stage source registers against the EX/MEM and MEM/WB destinations and drives the operand-A/B forwarding selects to eliminate most data hazards.
STALL_UNIT.vhd | Combinational hazard-detection unit. Detects load-use and multiply-use dependencies that forwarding cannot cover and inserts a single bubble (de-asserts PCwrite and the IF/ID enable).
FLUSH_UNIT.vhd | Control-hazard flush logic. On a taken branch or jump (resolved in stage 4) it squashes the wrong-path instructions sitting in the IF/ID and ID/EX registers.
aux_package.vhd | Auxiliary package: component declarations and helper functions/types shared across the design.
const_package.vhd | Constants package: bus widths, opcodes, ALU-operation codes and other design-wide parameters.
cond_compilation_package.vhd | Conditional-compilation package: switches that select build options / target-specific behaviour.

Table 4: Description of every HDL source file in the pipelined RV32IM design.

## 6. Elaborated Analysis and Waveforms

Functional validation was performed in ModelSim by running the benchmark applications and comparing the final data-memory image (DTCM.mem) against the RARS golden reference (DTCM.h). Figure 12 shows the ModelSim wave window for the pipelined RV32IM core. The waveform is organised into four signal groups: the testbench signals (clk, rst, BPADDR), the per-stage PC and instruction buses (IF/ID/EX/MEM/WB), the hazard / IPC counters, and the per-stage internal signals.

System timing is read directly from this capture. The five-stage structure is visible as a diagonal flow of a single PC value across the stage columns: a program-counter value appears first on IFpc_o, then one clock later on IDpc_o, then EXpc_o, MEMpc_o and finally WBpc_o – confirming that each instruction is staggered exactly one cycle per stage and that, after the initial five-cycle fill, one instruction is retired per clock in steady state. The corresponding instruction words shift through IFinstruction_o → … → WBinstruction_o in lock-step with the PC.

The hazard / IPC group makes the throughput penalties explicit. The stall counter STCNT_o increments on each load-use or multiply-use bubble (it is seen stepping 28 → 29 → 30 across the window), while the flush counter FHCNT_o increments when wrong-path instructions are squashed after a branch/jump resolves in stage 4 (shown reaching 14). The free-running clock counter CLKCNT_o advances every cycle (289 → 301 over the same span). These three registers feed the instruction-per-cycle calculation:
IPC = [CLKCNT_o − (STCNT_o + 4 + depth×FHCNT_o)] / CLKCNT_o,

where the constant 4 accounts for the initial pipeline fill and the flush penalty scales with the branch-resolution depth. Reading the cursor values from the capture (CLKCNT_o=301, STCNT_o=30, FHCNT_o=14) gives a measured IPC consistent with the instruction-count side of the equation, confirming correct pipeline timing for the benchmark.

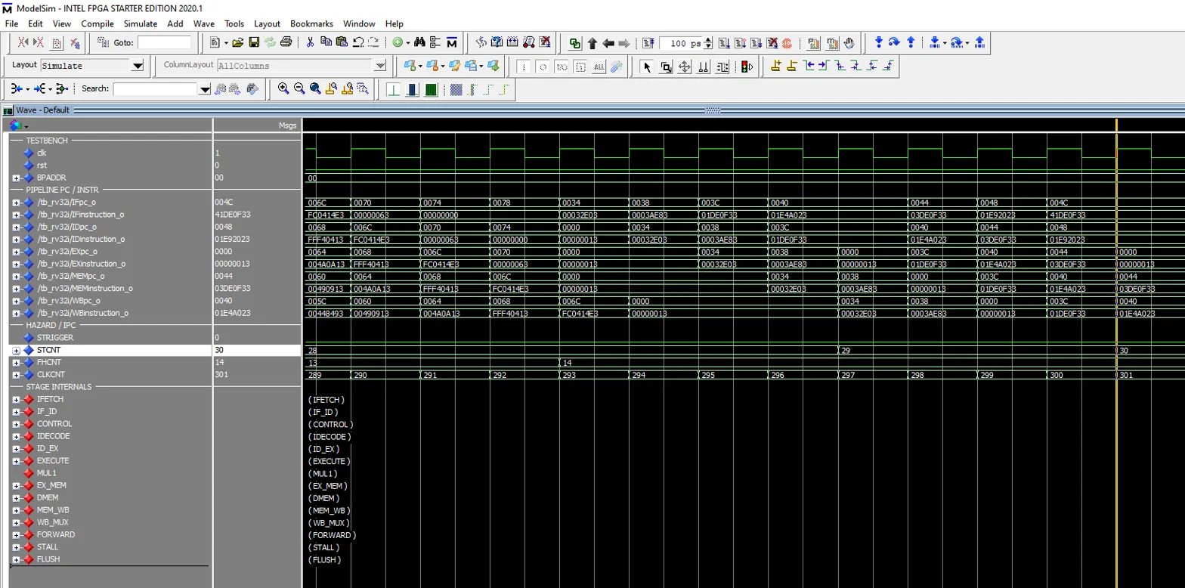
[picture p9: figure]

Figure 12: ModelSim wave window of the pipelined RV32IM core. The same PC value propagates diagonally across the IF→ID→EX→MEM→WB stage columns (one cycle per stage), while the STCNT_o / FHCNT_o / CLKCNT_o counters record stalls, flushes and elapsed clocks for the IPC measurement.

The design was additionally validated in-system on the DE10-Standard using SignalTap, capturing the core signals from the breakpoint address until the trace buffer filled; the on-hardware instruction count matched the ModelSim result, completing the design validation.

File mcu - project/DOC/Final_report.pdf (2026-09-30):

## final lab project - VHDL coding

Yuval Elron / 318676061
Amit Postelnik / 206458333

Project Goal
The goal of this project was to design, code and verify in VHDL a complete single-cycle RV32IM microcontroller system on an FPGA, and to extend it from a bare processor core into a working MCU with real memory-mapped peripherals and a hardware interrupt mechanism.

## Table of Contents

Pages

Project Goal | 1
part 1 – Top-level block diagram review | 3
1.1) MCU_TOP | 4
1.1.1) bidir_pin | 5
1.1.2) basic_timer_top | 7
1.1.2.1) addr_decoder_basic_timer | 8
1.1.2.2) basic_timer | 9
1.1.2.2.1) output_unit | 10
1.1.2.2.2) bit_timer | 11
1.1.3) pushbutton_peripheral | 12
1.1.4) interrupt_controller_top | 13
1.1.4.1) addr_decoder_interrupt | 14
1.1.4.2) interrupt_controller | 15
1.1.5) gpio_peripherals | 17
1.1.6) RV32-CORE | 19
1.1.7) sync and divider_accelerator | 21
2) PPA Characterization of RV32IM-Based MCU Design | 23
2.1) Supporting Quartus Reports – with interrupts | 24
2.2) MCU with GPIO only (no interrupts) | 27
3) SignalTap use | 30

part 1 : we will review the Top-level block review diagram of Ur design

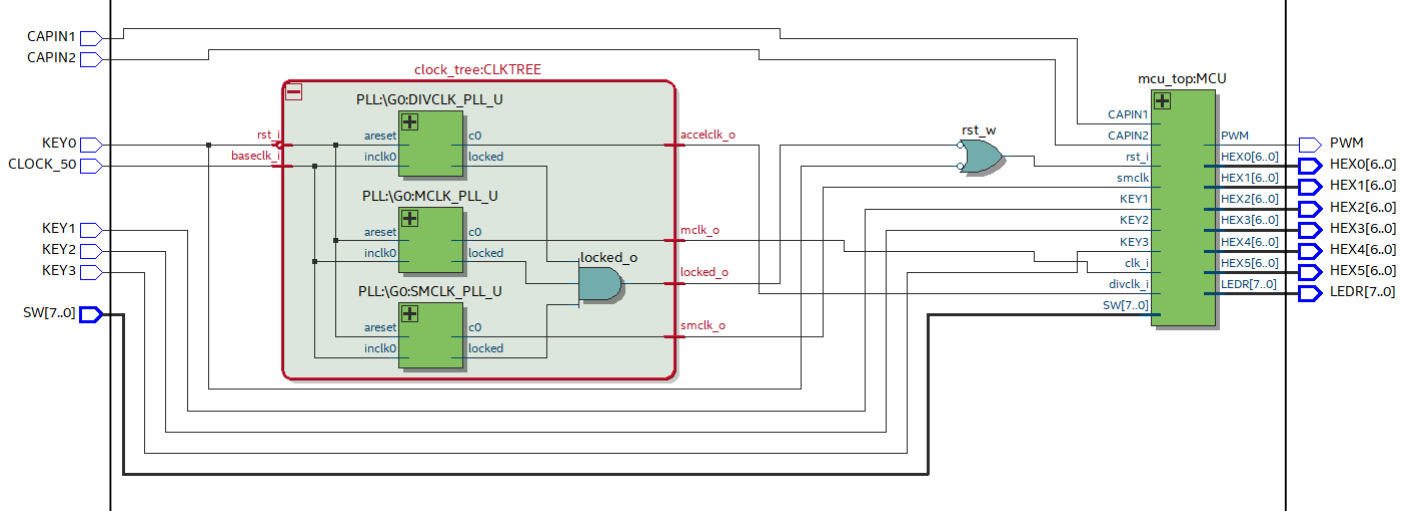
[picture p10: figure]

we will start by explaining etch components is our design and what its purposes.

here we can see in general the RTL of the top system on our MCU that named “MCU_SYSTEM” , a clock going to the “clock tree” component and 3 clk’s are going out from it : {mclk, smclk, divclk} - 3 pll use for outputting the corresponding clk frequency according for the unit its going to.

The values of {mclk, smclk, divclk} in set do to the quartus f_max analysis and are reduced a bit to avoid problems that can appear due to heat and FGPA slack.

from where is entering the MCU_TOP entity.

Picture 1 : MUC_SYSTEM

1.1) MCU_TOP

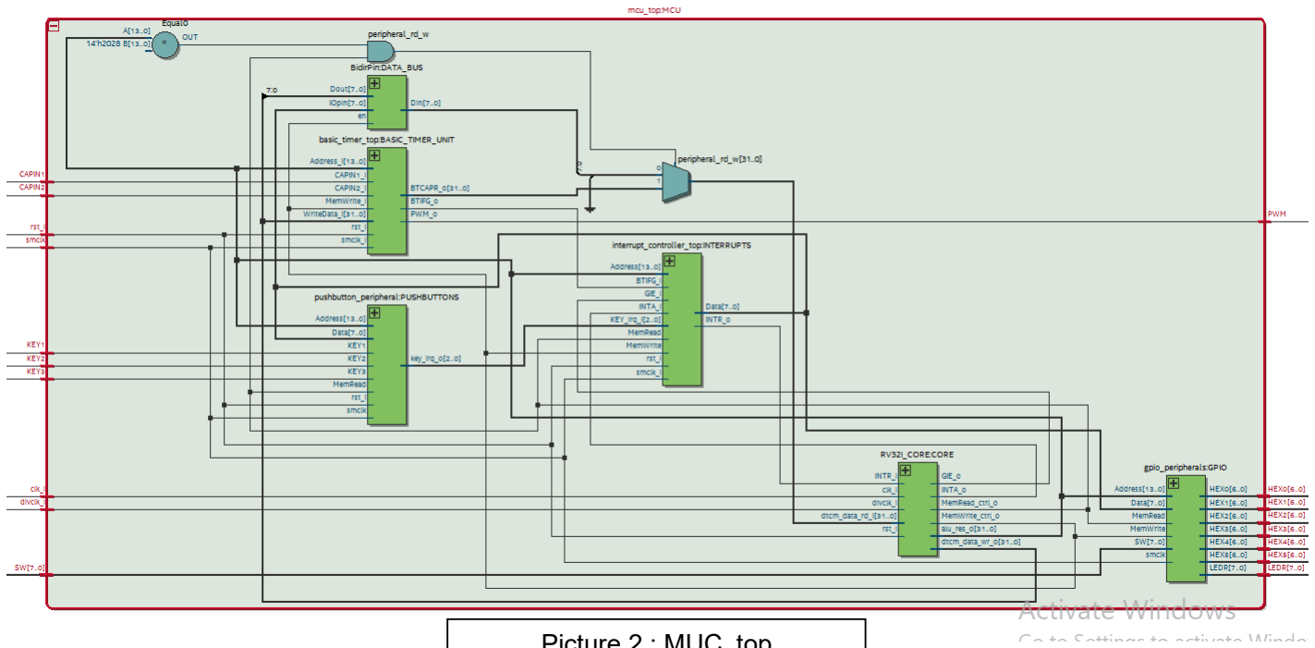
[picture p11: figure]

MCU_top is the structural container that wires the RISC‑V core to every memory mapped peripheral through the BUS Interface Logic.
It holds no functional logic of its own
it the upper-level entity of all other files in our project:

bidir_pin - To prevent the simultaneous transmission of two signals on the bus, while allowing the data bus to function and transfer information in both directions. basic_timer_top - This is the component that unifies all the timer rates and interfaces with the interrupt unit and the processor.
Pushbutton_periperihel - Detects button presses on KEY1–KEY3, generates interrupt requests, and allows the processor to read their states through the memory-mapped data bus
Interrupt_controler_top - Collects interrupt requests, applies enable and priority logic, identifies the interrupt source, and manages the interrupt handshake with the processor.
RV32-core - Executes the program instructions and performs arithmetic, memory, control-flow, multiplication, division, and interrupt-handling operations. Gpio_pariperihel - Provides the memory-mapped interface between the processor and the switches, LEDs, and seven-segment displays, supporting both input reads and output writes.

Picture 2 : MUC_top

1.1.1)bidir_pin:

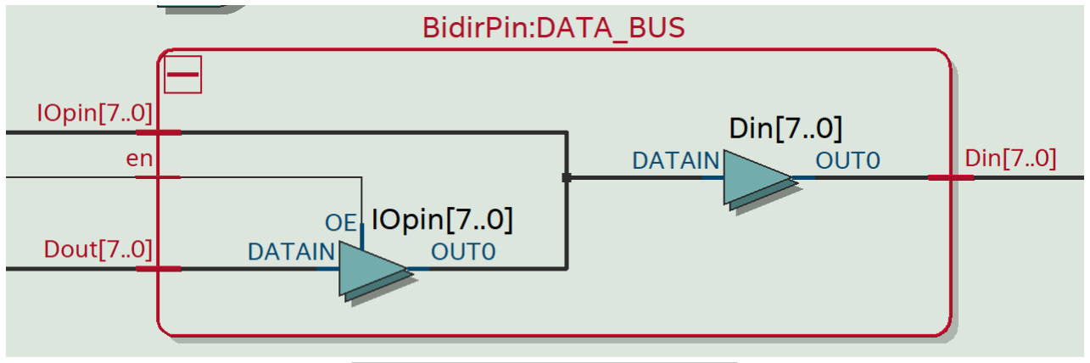
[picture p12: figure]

BidirPin is a generic tri-state buffer, it is the component that realises the bi-directional Data BUS of the system architecture.
Dout is driven onto the shared IOpin net whenever en is high and released to high impedance otherwise, while Din continuously reads back whatever is currently present on that net.
In mcu_top en is the CPU MemWrite signal, so the core owns the bus during a store and releases it during a load, letting the addressed peripheral drive the data instead. That same release is what allows the interrupt controller to place TYPE on the bus during active-low INTA without using the address bus.

Picture 3 : BidirPin

Interrupt expiation:

One of the requirements of this project was to add interrupt capability and a Basic Timer to the MCU. Interrupt capability means the CPU no longer has to keep polling the peripherals in software: a peripheral can raise a request by itself, and the hardware makes the processor stop what it is doing, jump to a service routine, and come back afterwards to exactly the instruction it left. The Basic Timer is one of those sources, and it also gives the system a sense of time, since it can count, generate a PWM output, and capture the counter value on an external event.

In our design this is implemented by three pieces working together.
The peripherals produce the requests: pushbutton_peripheral turns a press of KEY1 to KEY3 into a single-cycle event, and basic_timer raises BTIFG when its counter reaches a compare value or when a capture happens.
The interrupt controller stores these events in IFG, masks them with IE, chooses the most important one with a priority encoder, gives it a vector number in TYPE, and raises INTR to the CPU. The CPU side, inside CONTROL and IDECODE, answers with INTA, disables further interrupts, reads the handler address from the vector table and saves the return address, so the routine can run and reti can bring the program back.
The result is that software only has to write IE once and provide the handlers, and everything after that happens in hardware.
The architecture we built utilizes and addresses the aforementioned memory location.
A LOAD operation targeting the relevant address is the one that sends or receives data.

Picture 4 : memory – mapped

1.1.2)basic_timer_top:

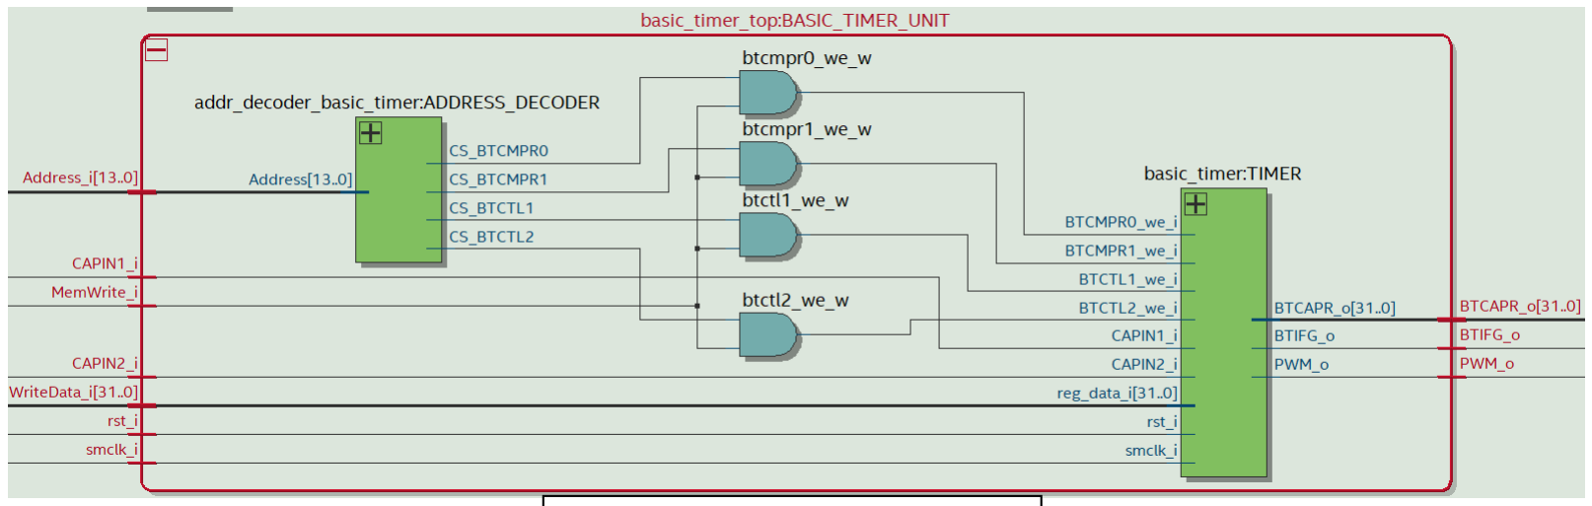
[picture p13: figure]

basic_timer_top is the structural wrapper of the Basic Timer, and it contains only the address decoder, the timer itself, and the write-enable gating between them. The decoder turns the shared 14-bit address into the four chip selects CS_BTCTL1, CS_BTCTL2, CS_BTCMPR0 and CS_BTCMPR1, and each of them is ANDed with MemWrite_i so that a timer register is loaded only during a valid CPU write to its own address.
CS_BTCAPR is deliberately left unconnected because BTCAPR is a capture-only register that hardware writes and software can only read, and its 32-bit value is returned to the core through the dedicated multiplexer in mcu_top.
The full 32-bit WriteData_i is passed straight through as reg_data_i, since BTCMPR0 and BTCMPR1 are word registers while BTCTL1 and BTCTL2 use only the low byte, and CAPIN1/CAPIN2 pass through untouched to the capture logic, with BTCAPR_o, BTIFG_o and PWM_o leaving as the unit's system outputs.

The two blocks inside it, addr_decoder_basic_timer and basic_timer, are described separately below.

Picture 5 : basic_timer_top

1.1.2.1) adder_decoder_basic_timer :

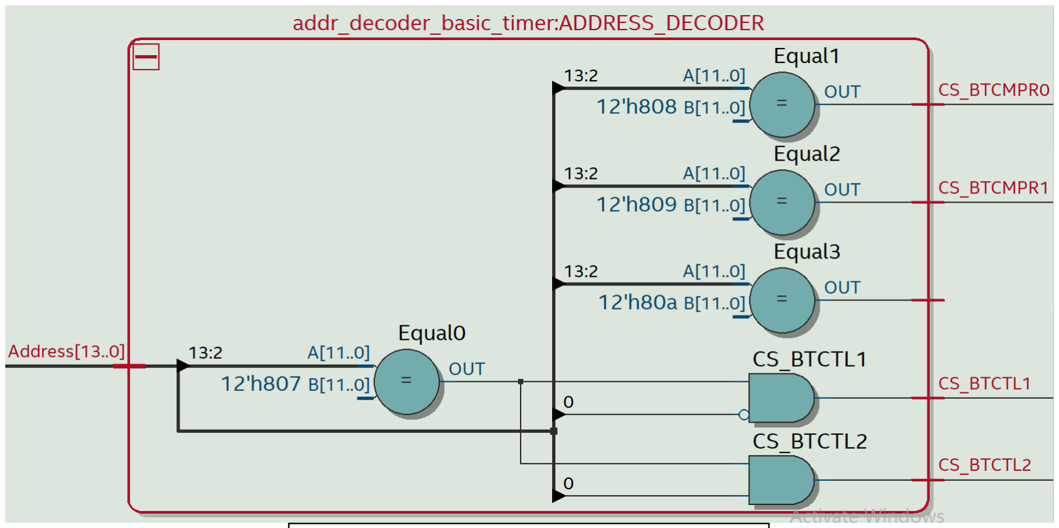
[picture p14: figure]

adder_decoder_basic_timer decodes the address bus and produces one chip select per timer register.
His general purpose is to give you information - how do we need to address it now?

It compares the upper address bits, Address(13 downto 2), against 12'h807, 12'h808, 12'h809 and 12'h80A, which are the byte addresses 0x201C, 0x2020, 0x2024 and 0x2028.
BTCTL1 and BTCTL2 sit in the same word, so the 12'h807 match is split by Address(0): low gives CS_BTCTL1 and high gives CS_BTCTL2. CS_BTCAPR is left unused, because BTCAPR is written by the capture logic and read back through the separate 32-bit path in mcu_top.

Picture 6 : RTL of adder_decoder_basic_timer

1.1.2.2) basic_timer:

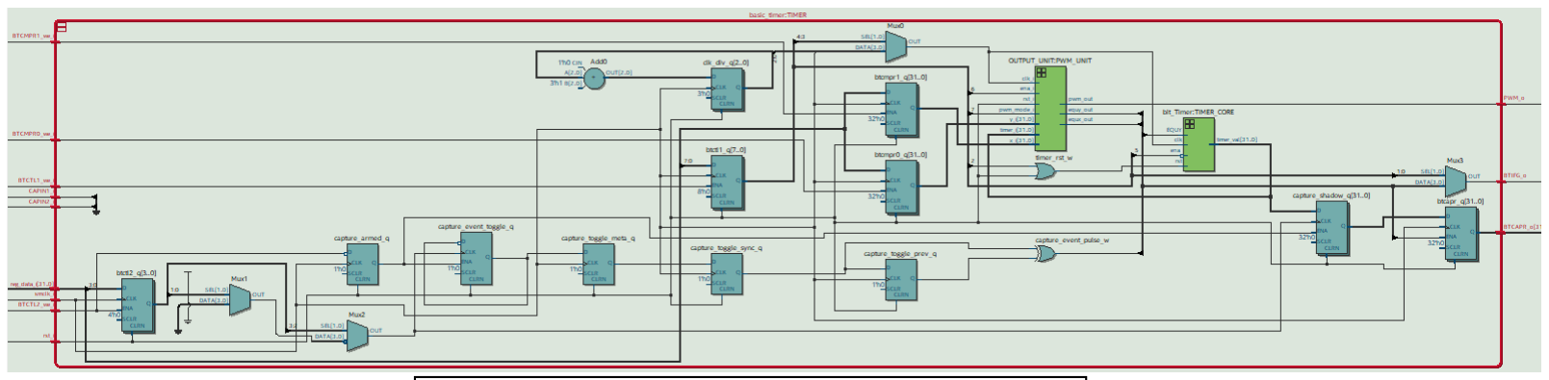
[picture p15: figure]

basic_timer is the actual timer: it holds the memory-mapped registers BTCTL1, BTCTL2, BTCMPR0 and BTCMPR1, and drives the counter, the PWM output and the capture logic from them.
BTCTL1 selects the counter clock through a small divider (BTSSEL), holds or clears the counter (BTHOLD, BTCLR) and chooses which event raises BTIFG (BTINT), while the counter itself is the bit_Timer:TIMER_CORE block and the compare and PWM generation happen in OUTPUT_UNIT:PWM_UNIT.
BTCTL2 controls capture: two multiplexers pick the capture source (CAPIN1, CAPIN2, VCC or GND) and the active edge, and on that edge the current counter value is stored in capture_shadow_q.
Because the capture edge is asynchronous to smclk, the event is passed as a toggle bit through two synchronizer flip-flops and turned back into a one-cycle pulse, which then loads BTCAPR and can also be selected as the BTIFG source.

The blocks inside it, bit_Timer and OUTPUT_UNIT, are described separately below:

Picture 7 : RTL of basic_timer

1.1.2.2.1) output_unit

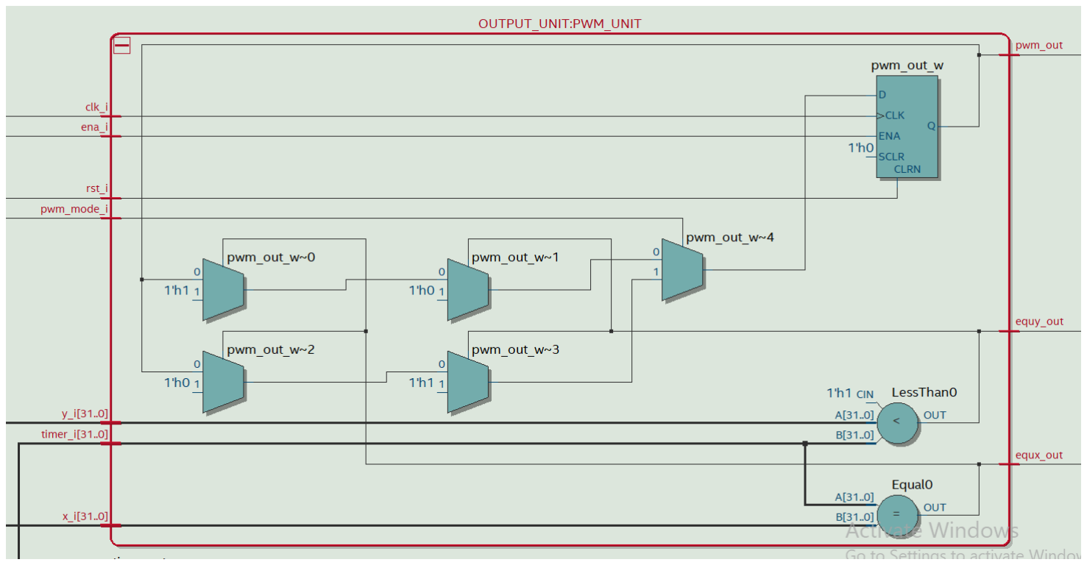
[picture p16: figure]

The core responsibility of the OUTPUT_UNIT is to compare the timer counter with the two compare registers and build the PWM signal from the result.

equy_out goes high when the counter reaches BTCMPR0, which sets the PWM period, and equx_out goes high when the counter equals BTCMPR1, which sets the duty cycle.

The flip-flop at the output turns these two events into a square wave: one match sets it and the other clears it, pwm_mode_i swaps which is which, and ena_i (BTOUTEN) holds the output frozen when the PWM is off.
equy_out is also sent back to the counter to reset it at the end of every period, and both compare signals can be chosen as the timer interrupt source.

Picture 8 : RTL of output_unit

1.1.2.2.2) bit_timer

bit_Timer is the counter itself, a plain 32-bit up-counter.
On every clock edge, if ena is high, the adder adds 1 to the current value and stores it back in count_q.
The multiplexer next to the adder handles the wrap: when EQUY comes back from the compare unit the counter is loaded with zero instead, so it restarts at the end of each period.
rst clears it asynchronously, ena comes from BTHOLD so software can freeze it, and the value leaves as timer_val, which is BTCNT.
This unit is working with the OutPut_Unit.

Picture 9 : RTL of bit_timer

1.1.3) pushbutton_periperihel

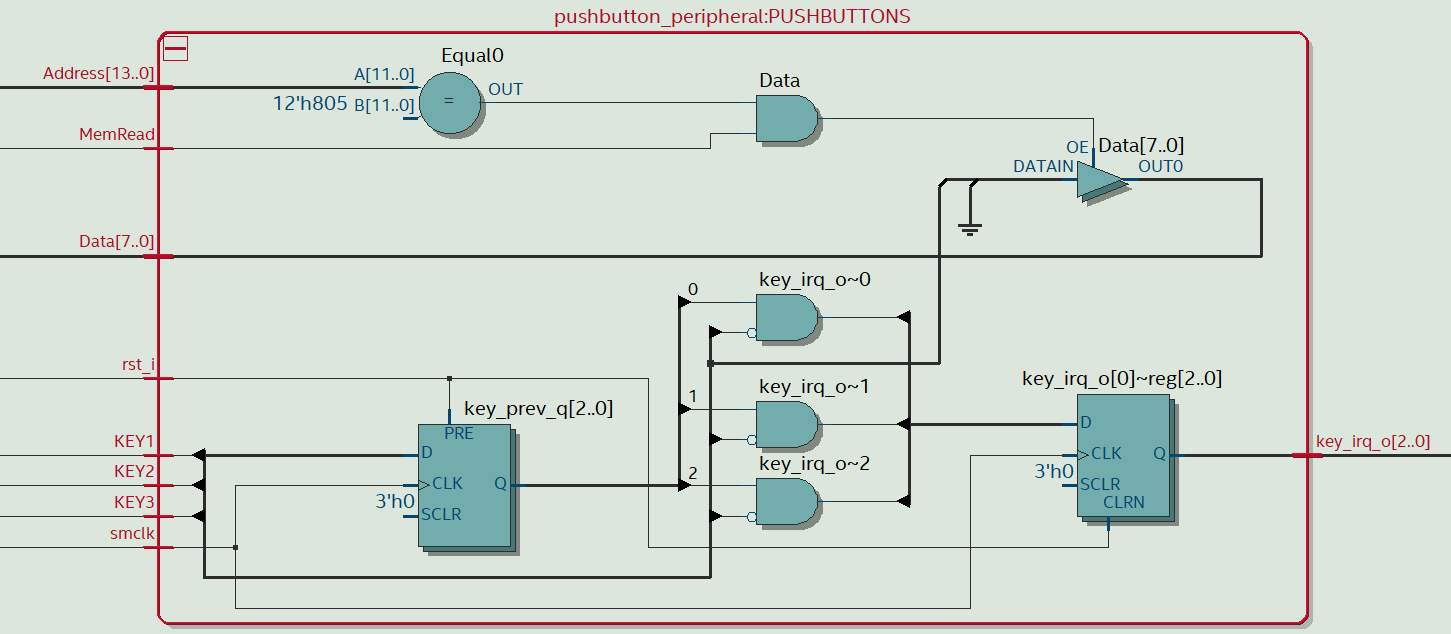
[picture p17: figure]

pushbutton_peripheral handles the three pushbuttons KEY1 to KEY3 and does two separate jobs.

1) is the read port: Equal0 compares the address against 12'h805, which is byte address 0x2014 (PORT_PB), and together with MemRead it enables a tristate driver that puts the current button levels on the data bus, so software can read the buttons directly.
2) is edge detection for interrupts: key_prev_q samples the three buttons on every smclk edge, and the AND gates compare the previous sample with the current level to detect a high-to-low transition, since the buttons are active low.
The result is registered again into key_irq_o, so each press produces a single one-cycle pulse per button, and these three pulses are what set the KEY1, KEY2 and KEY3 flags in the interrupt controller.

Picture 10 : RTL of PushButton_Periperihel

1.1.4) interrupt_controler_top

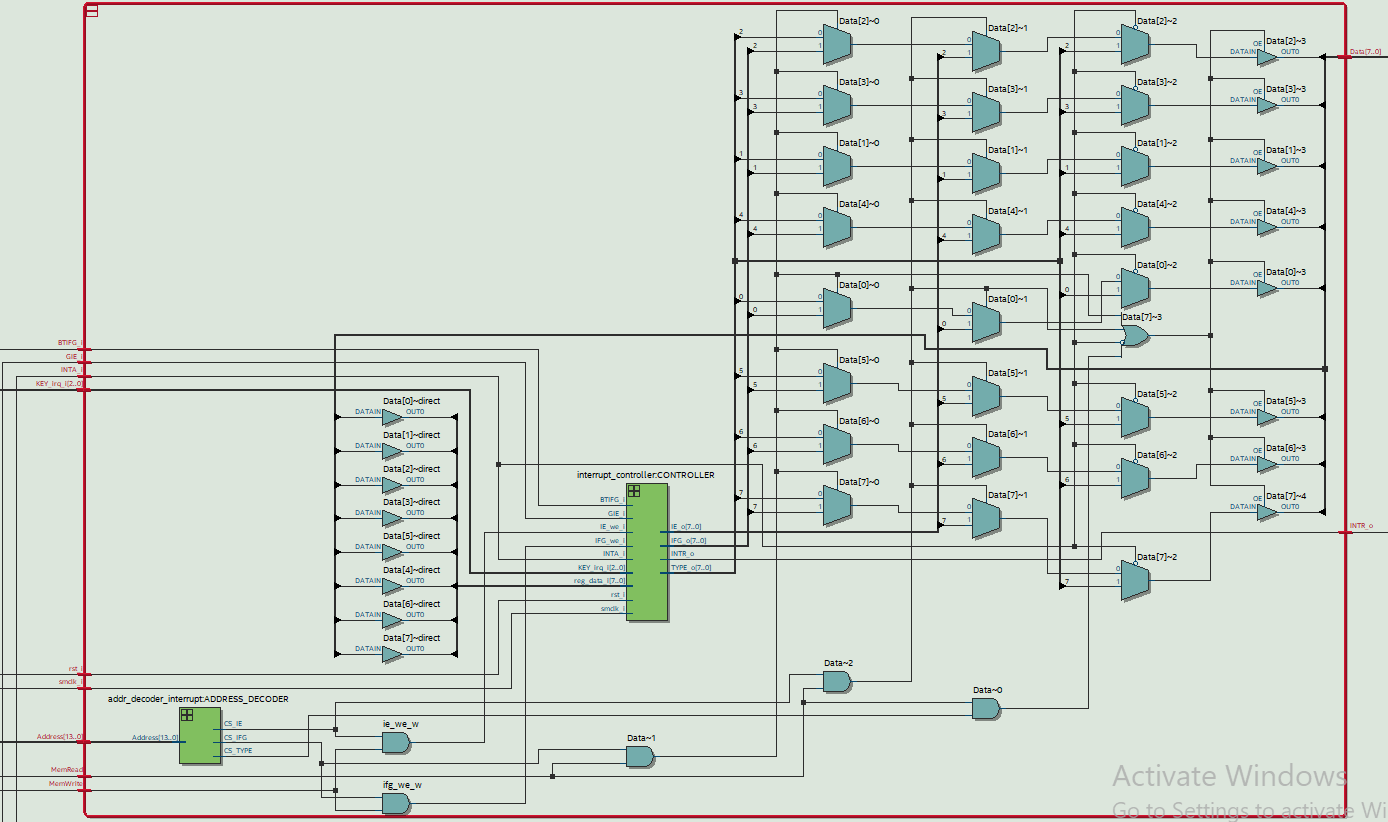
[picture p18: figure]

interrupt_controller_top is the box that connects the interrupt controller to the shared bus. The address decoder checks which of the three registers the CPU is talking to, IE, IFG or TYPE, and the two AND gates make sure a register is only written when the CPU is really doing a write.
The buffers on the left let the CPU's data come into the block, so software can set IE and IFG.
The multiplexers on the right choose which of the three registers is sent back to the CPU, and TYPE always wins when INTA is low, so the CPU gets the interrupt number during the acknowledge.
The tri-state buffers at the edge let the block release the bus when it is not being used, so other peripherals can drive it instead.

The block inside it “adder_decoder_interrupt” and “interrupt_controller” is described separately below.

Picture 11 : RTL of interrupt_controler_top

1.1.4.1) adder_decoder_interrupt

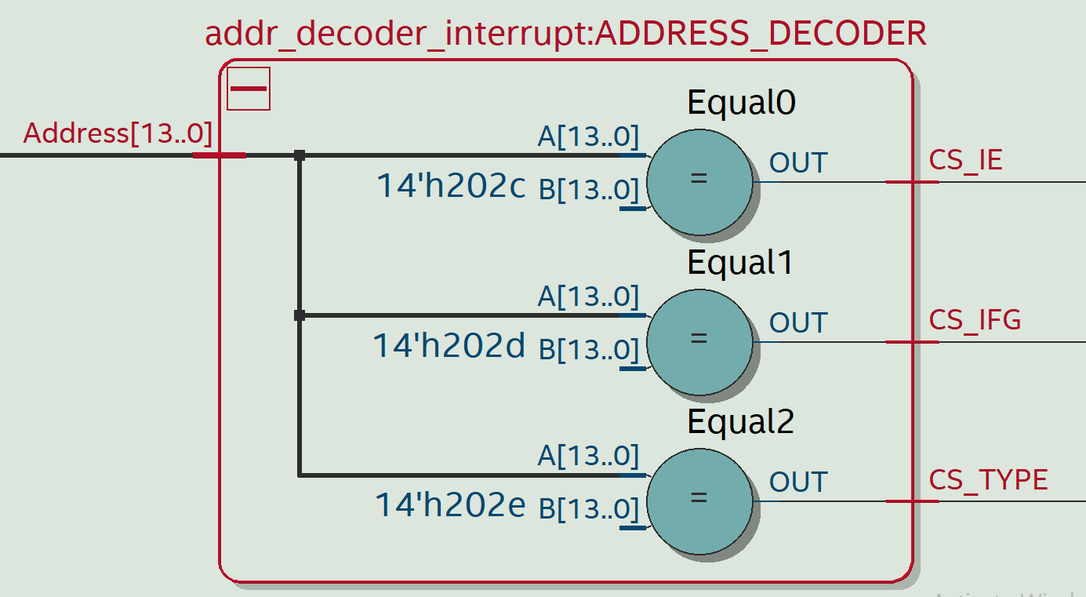
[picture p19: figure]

addr_decoder_interrupt tells the interrupt controller which of its registers the CPU is addressing.
It takes the 14-bit address and compares it with three fixed values, 0x202C for IE, 0x202D for IFG and 0x202E for TYPE, using one comparator each.
Only one of the three outputs can be high at a time, since the addresses are different.
These chip selects are then used outside the block, together with MemWrite and MemRead, to decide which register is written and which one is placed back on the data bus.

Picture 12 : RTL of interrupt_controler_top

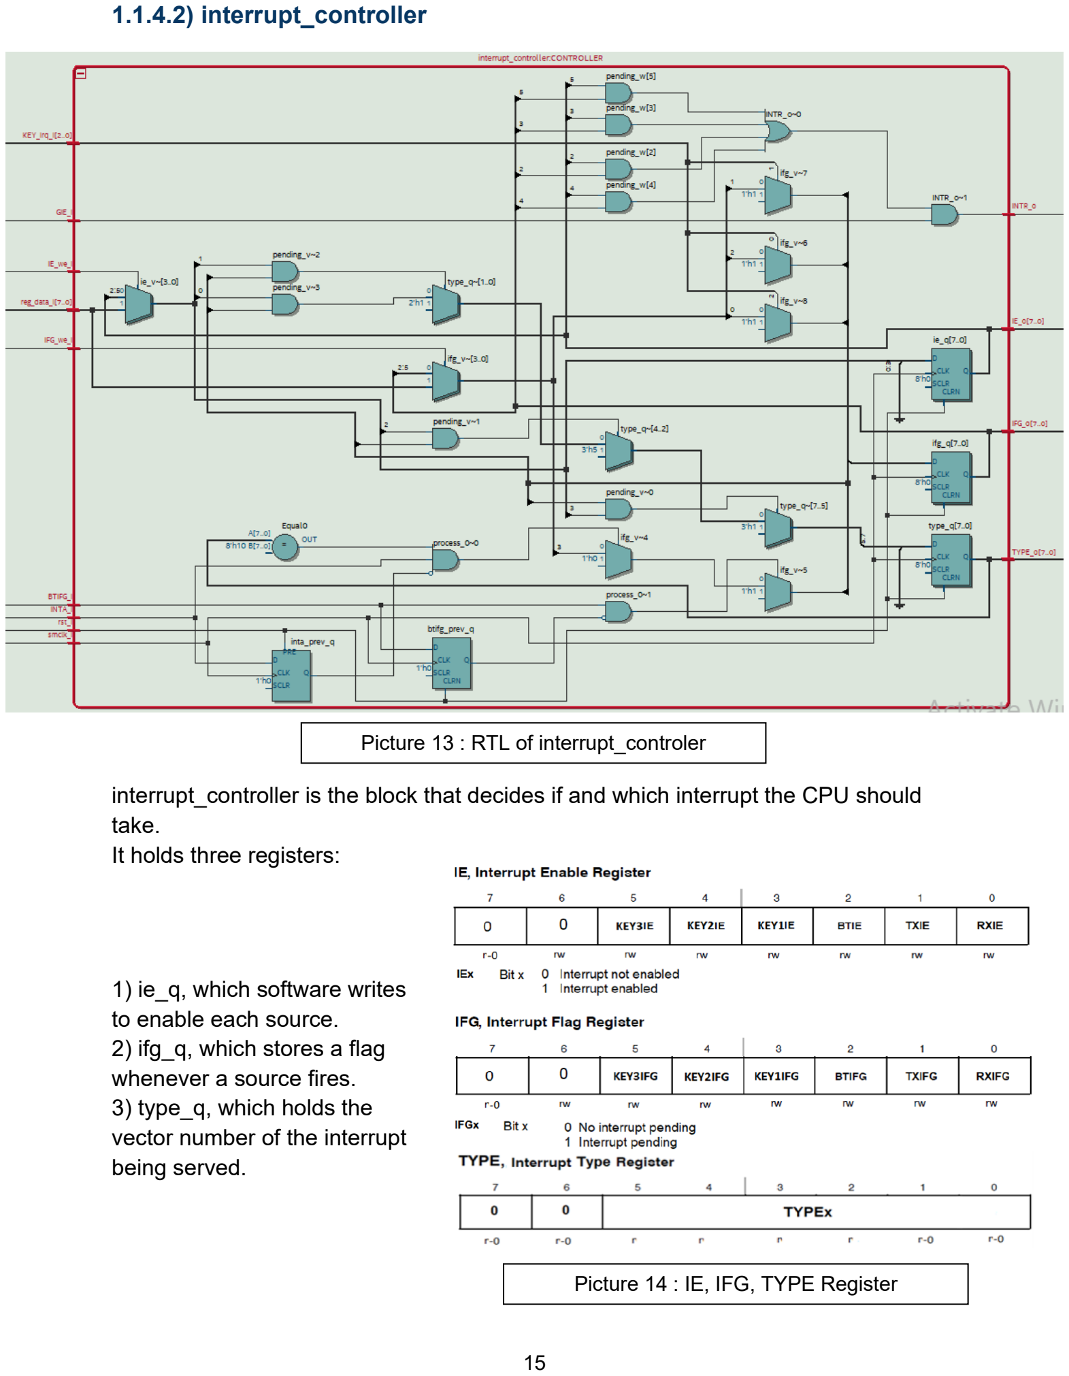
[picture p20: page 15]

1.1.4.2) interrupt_controller

interrupt_controller is the block that decides if and which interrupt the CPU should take.
It holds three registers:
1) ie_q, which software writes to enable each source.
2) ifg_q, which stores a flag whenever a source fires.
3) type_q, which holds the vector number of the interrupt being served.

Picture 13 : RTL of interrupt_controler

Picture 14 : IE, IFG, TYPE Register

The multiplexers around ifg_q are the ways a flag can change: a source event sets it, a software writer can set or clear it, and the timer flag is also cleared automatically after the acknowledge, with the source event given priority so a new request is never lost.
The AND gates named pending are simply ie_q and ifg_q bit by bit, meaning a source that is both enabled and flagged, and the OR gate combines them with GIE to produce INTR_o, the request line to the CPU. The chain of multiplexers feeding type_q is a priority encoder: it picks 0x10 for the Basic Timer, then 0x14, 0x18 and 0x1C for KEY1, KEY2 and KEY3, so if several interrupts are pending at once the CPU is given the most important one first.
The two small flip-flops at the bottom, inta_prev_q and btifg_prev_q, remember the previous value of INTA and BTIFG so the block can react to edges rather than levels.

Picture 15 : the DTCM eldresses list that store where we need to jump to -corresponding to etch Service ration

1.1.5) gpio_pheriperihal :

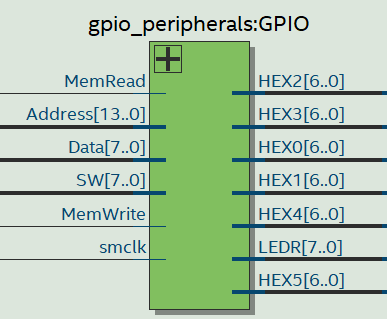
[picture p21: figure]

gpio_peripherals is the block that controls the simple things on the board: the red LEDs, the six digit displays and the slide switches. It is built from four small parts. in dis file we have 4 sub_files:

1- addr_decoder_gpio; looks at the address and decides which port the CPU is talking to, the LEDs, one of the displays, or the switches. Its outputs are combined with MemWrite to make a write signal, and with MemRead to make a read signal. corresponding to the fowling table

one instance. It compares the address bits against five fixed values and decides which port the CPU is talking to: the LEDs at 0x2000, the HEX0/HEX1 pair, the HEX2/HEX3 pair, the HEX4/HEX5 pair, or the switches at 0x2010. Each pair shares one chip select because the two ports sit in the same word, so address bit 0 separates them afterwards.

Picture 16 : RTL of Gpio_pheriperihal

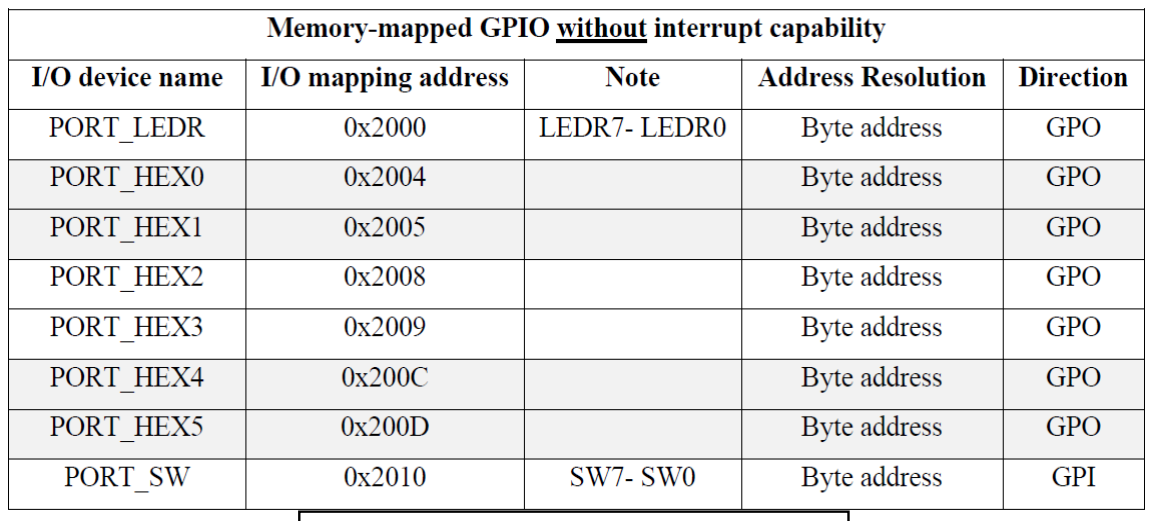
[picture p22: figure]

Picture 18 : Gpio map table

Picture 17 : RTL of adder_secoder_pgio

2 - hex7seg_decoder,
six instances. Each one takes the low four bits from its latch and converts that hexadecimal digit into the seven segment pattern that lights up one display.

3- tristate_byte,
eight instances. These are what allow reading over the shared bidirectional data bus. Seven of them send back the byte currently stored in the LED and display latches, so software can read a port it wrote earlier, and the eighth places the switch inputs SW7 to SW0 on the bus. Each driver turns on only when its own read enable is high and is released otherwise, so only one source drives the bus at a time.

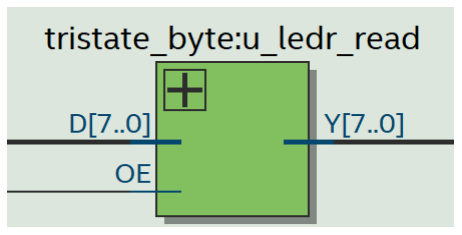
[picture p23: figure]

4- d_latch_byte,
seven instances. Each one is an 8-bit storage element that keeps the byte the CPU wrote, one for the LEDs and one for every display digit, so the value stays on the board until the next write. The latch opens only while smclk is low, because that is when the address bus is stable and the byte is guaranteed to land in the correct port.

Picture 19 : hex7seg_decoder

Picture 20 : tristate_byte

Picture 21 : d_latch_byte

1.1.6) RV32-CORE :

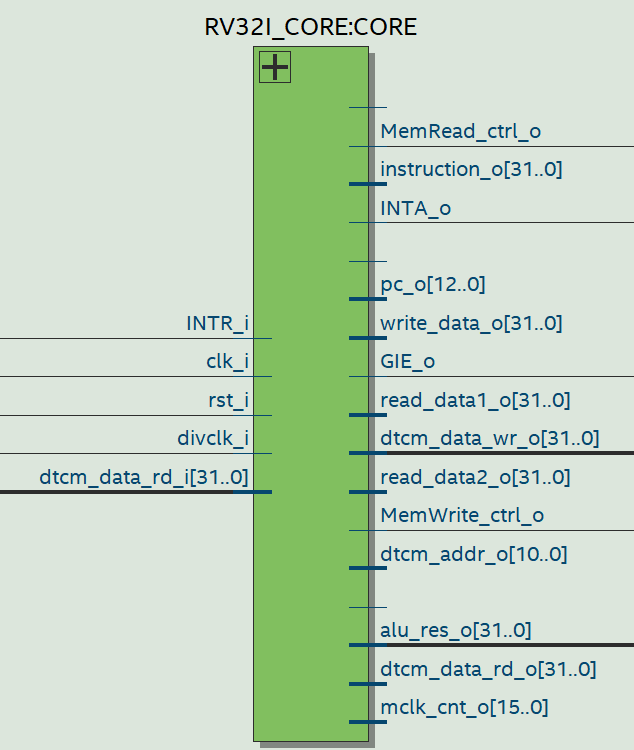
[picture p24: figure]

RV32I_CORE is the CPU. It is a single-cycle RV32IM processor, built from smaller blocks: fetch, decode, execute, control, data memory, a multiplier and a division accelerator.

Its inputs are the CPU clock, the faster clock for the divider, the reset, the data coming back from a peripheral, and INTR_i, the interrupt request.

Its main outputs are the address it wants to access, the data it wants to store, and two signals that say whether this is a read or a write. These four are what the bus in mcu_top uses to reach every peripheral.

INTA_o and GIE_o are the interrupt handshake: INTA answers the controller, and GIE says whether interrupts are allowed right now.

All the other outputs, like pc_o and instruction_o, are not used by the design. They are brought out only so we can watch them in Signal Tap and measure performance.

Picture 22 :RTL of RV32-CORE

To support interrupts, changes were added to some of the blocks, while others are reused as they are.

IFETCH: no new logic was added. The interrupt reuses the PC hold input, which freezes the program counter for one cycle, and the JALR target input, which is used as a fake jump to the handler address.

IDECODE: two registers were given a special role. GIE is bit 0 of gp (x3), so the hardware can clear it when an interrupt starts and set it again on reti, and it is also sent out to the interrupt controller. The return address is written into tp (x4), which is what reti jumps back to.

CONTROL: a small state machine was added. It waits for INTR, then runs two cycles: in the first it sends INTA, freezes the PC and clears GIE, and in the second it latches TYPE and starts the jump. It also blocks all control signals during those two cycles, so the instruction that was fetched does nothing.

EXECUTE: no change. The ALU is not involved in the interrupt sequence, because the handler address comes from memory and not from a calculation.

DMEMORY: no change. It is simply given TYPE as its address during the second cycle, so it reads the vector table entry that holds the address of the handler.

1.1.7) sync and divider_accelarator


sync is the bridge between the two clocks.
NOTE that and entry of read_data1 and read_data2 are from enter 2 registers that are in the rv32-core and controlled by mclk.

The CPU and the divider operate with different clocks.
The CPU uses the slower MCLK, while the divider uses the faster DIVCLK. Therefore, the two operands pass through two flip-flop stages before entering the divider. This gives the signals enough time to become stable in the fast-clock domain. The synchronized outputs ain_o and bin_o are used as the dividend and divisor.

The divider_accelerator performs unsigned division using the restoring-division algorithm. divrst_i loads the operands and initializes the divider, while divena_i starts the operation.
The divider calculates one quotient bit on every rising edge of DIVCLK, so a complete 32-bit division requires 32 fast-clock cycles. While it is working, divbusy_o remains high and tells the CPU to wait. When the operation finishes, quotient_o contains the division result and rem_o contains the remainder.

The divider also interacts with the interrupt mechanism. If an interrupt arrives while a division is running, the processor waits until the division finishes before accepting it. This prevents the division instruction from being interrupted, restarted, or completed with incorrect operands. Both mechanisms can hold the program counter through the PC-hold logic.
As a result, interrupt response may be delayed by up to one complete division operation.

Picture 23 :RTL of sync and divider_accelarator how interrupt flow in the design:
1 - The press. KEY1 to KEY3 are active low. In pushbutton_peripheral the three buttons are sampled on every smclk edge into key_prev_q, and comparing the previous sample with the current level produces a single one-cycle pulse on the falling edge, on key_irq_o.

2- The flag is stored. In interrupt_controller that pulse sets the matching bit of ifg_q, bit 3 for KEY1, bit 4 for KEY2 and bit 5 for KEY3. The flag stays set until someone clears it, so a short press is never lost.

3- The request is formed. The controller computes pending as ie_q AND ifg_q, so only sources the software enabled through IE can pass. A priority encoder loads type_q with the vector number of the most important pending source, 0x10 for the Basic Timer and 0x14, 0x18, 0x1C for KEY1, KEY2 and KEY3, and INTR_o goes high if anything is pending and GIE is set.

4- The CPU accepts. In CONTROL the interrupt state machine leaves idle only if INTR is high and the divider is not stalling, so a division in progress always finishes first.

5- First cycle, acknowledge. CONTROL drives INTA low, freezes the program counter through the PC hold input of IFETCH, and asks IDECODE to clear GIE, which is bit 0 of gp (x3), so no second interrupt can enter. Because INTA is low, interrupt_controller_top gives TYPE the highest priority on the data bus and drives it without any address, and CONTROL latches it. All control signals are blocked in this cycle, so the instruction that was fetched does nothing.

6- Second cycle, service. RV32I_CORE replaces the data address with the zero extended TYPE value, so DMEMORY reads the vector table entry at Memory[TYPE], which holds the address of the handler. In the same cycle IDECODE writes the return PC into tp (x4), and the core reuses the JALR path of IFETCH with that memory read as the target, so the next instruction fetched is the first instruction of the handler.

7- The handler runs. From here everything is ordinary instruction execution. GIE is zero, so the routine cannot be interrupted, and before returning it clears its own flag by reading IFG, masking the bit and writing the value back. That write passes the address decoder and the MemWrite gate in interrupt_controller_top and reaches ifg_q, which makes pending drop and INTR go low.

8- The return. reti is simply jalr zero, 0(tp), so it is executed as a normal jump through EXECUTE and IFETCH and the PC returns to the instruction that was interrupted. CONTROL detects it while in the idle state and asks IDECODE to set GIE back to one, so the next interrupt can be accepted.

2) PPA Characterization of RV32IM-Based MCU Design

Area

| Logic utilization (ALMs) | Registers | I/O pins | Embedded memory bits | DSP blocks | PLLs
MCU with GPIO | 1,779 / 41,910 (4%) | 1,796 | 66 / 499 (13%) | 131,072 / 5,662,720 (2%) | 3 / 112 (3%) | 2 / 15 (13%)
MCU with GPIO & interrupt | 1,916 / 41,910 (5%) | 1,811 | 66 / 499 (13%) | 131,072 / 5,662,720 (2%) | 3 / 112 (3%) | 2 / 15 (13%)

Performance

| fmax | Critical path (slowest submodule and reason) | fMCLK (= fsysclk)
MCU with GPIO | 31.71 MHz | Divider accelerator dividend register → accelerator write-back multiplexers → Register File write port (DIV_INST|dividend_q[36] → Idecode:ID|RF_q[22][4]). DIVCLK-launched / MCLK-captured cross-domain transfer. Setup slack = 0.411 ns. | 25 MHz
MCU with GPIO & interrupt | 29.87 MHz | Divider accelerator dividend register → accelerator write-back multiplexers → Register File write port (DIV_INST|dividend_q[46] → Idecode:ID|RF_q[4][14]). DIVCLK-launched / MCLK-captured cross-domain transfer with an 8.000 ns launch-to-latch relationship. Setup slack = 0.130 ns (second-worst path 0.353 ns). | 25 MHz

Power

| Total power consumption | Static power consumption | Dynamic power consumption | I/O power consumption
MCU with GPIO | 470.89 mW | 419.23 mW | 40.95 mW | 10.71 mW
MCU with GPIO & interrupt | 470.14 mW | 419.22 mW | 40.21 mW | 10.71 mW

2.1) Supporting Quartus Reports - WITH INTERRUPTS

Figure 24 – Quartus Prime Flow Summary: MCU with GPIO and interrupt capability (revision LAB_5_PIP, Cyclone V 5CSXFC6D6F31C6 – 1,916 ALMs, 1,811 registers).

Figure 25 – Slow-model clock summary, interrupt-enabled build: Fmax per clock domain (MCLK PLL divclk = 29.87 MHz, DIVCLK PLL divclk = 152.93 MHz, altera_reserved_tck = 86.41 MHz).

Figure 26 – Critical path summary: worst-case setup slack 0.130 ns, divider accelerator dividend_q[46] (DIVCLK) → register file RF_q[4][14] (MCLK), 8.000 ns clock relationship.


Figure 27 – RTL/technology-map view of the divider-accelerator datapath along the reported critical path.

The worst-case path starts at the divider accelerator's dividend register (divider_accelerator:DIV_INST|dividend_q[46]), passes through the divider's quotient/remainder selection and result-multiplexing logic, and terminates at the register-file write port in the decode stage (Idecode:ID|RF_q[4][14]). It is a cross-domain path: the source register is launched by the DIVCLK PLL output while the destination is captured by the MCLK PLL output, giving a launch-to-latch relationship of only 8.000 ns. With a data arrival time of 41.006 ns against a required time of 41.136 ns, the remaining setup slack is 0.130 ns, making the divider result transfer the tightest timing constraint in the interrupt-enabled build. The second-worst path is the same structure one bit-slice over (dividend_q[38] → RF_q[28][6]) with 0.353 ns slack, confirming that the whole divider write-back bus, and not a single bit, is the limiter.


Figure 28 – Second-worst setup path: slack 0.353 ns, divider accelerator dividend_q[38] (DIVCLK) → register file RF_q[28][6] (MCLK); arrival 40.787 ns vs. required 41.140 ns.


Figure 29 – Power Analyzer Summary, interrupt-enabled build: 470.14 mW total (419.22 mW static, 40.21 mW dynamic, 10.71 mW I/O); confidence Low.


2.2) MCU WITH GPIO ONLY (NO INTERRUPTS)

Figure 30 - Quartus Prime Flow Summary: MCU with GPIO, no interrupt capability (1,779 ALMs, 1,796 registers).

Figure 31 - Slow-model clock summary: Fmax per clock domain (MCLK PLL divclk = 31.71 MHz, DIVCLK PLL divclk = 156.52 MHz, altera_reserved_tck = 97.3 MHz).

Figure 32 - Critical path summary: worst-case setup slack 0.411 ns, divider accelerator dividend_q[36] (DIVCLK) → register file RF_q[22][4] (MCLK); arrival 40.726 ns vs. required 41.137 ns.


Figure 33 - RTL/technology-map view of the divider-accelerator write-back datapath along the reported critical path.


Figure 34 - Power Analyzer Summary, no-interrupt build: 470.89 mW total (419.23 mW static, 40.95 mW dynamic, 10.71 mW I/O); confidence Low.


Figure 35 - RTL/technology-map view of the divider-accelerator datapath along the reported critical path.
The worst-case path starts at the divider accelerator's dividend register (divider_accelerator:DIV_INST|dividend_q[46]), passes through the divider's quotient/remainder selection and result-multiplexing logic, and terminates at the register-file write port in the decode stage (Idecode:ID|RF_q[4][14]). It is a cross-domain path: the source register is launched by the DIVCLK PLL output while the destination is captured by the MCLK PLL output, giving a launch-to-latch relationship of only 8.000 ns. With a data arrival time of 41.006 ns against a required time of 41.136 ns, the remaining setup slack is 0.130 ns, making the divider result transfer the tightest timing constraint in the interrupt-enabled build.

3) signal tap use:


SignalTap was used to monitor the MCU’s internal signals directly on the FPGA. It captured the interrupt protocol, timer activity, program counter, and control signals in real time. A trigger was configured to start the capture when a selected interrupt event occurred. The recorded waveforms helped verify the correct timing and operation of the complete hardware system.

This screenshot is from test4 of inturrpt :
After KEY3 is pressed, the interrupt controller starts the interrupt sequence: INTR is detected, INTA acknowledges it, IRQhold freezes the PC, and IRQservice remains active while the ISR runs. The ISR selects State 3 and configures the Basic Timer for capture mode.
The timer is then cleared and counts during the division/remainder routine. When the routine ends, a capture event copies the current counter value into BTCAPR.
The displayed value 0xCC equals 204 SMCLK cycles, representing the measured execution time; at 25 MHz, this is approximately 8.16 µs

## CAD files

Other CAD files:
mcu - project/Quartus/RV32IMscMCU/stp1.stp
risc v cpu - project/Quartus/RV32IM_pipline/stp1_pipline.stp
risc v cpu - project/Quartus/RV32IM_sc/stp2.stp

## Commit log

2026-09-30 Replace repository contents with current project
    [stp1.stp]
2026-09-30 Group project files under mcu - project
    [stp1.stp]
2026-09-30 Add RISC-V CPU project files
    [stp1_pipline.stp, stp2.stp]
